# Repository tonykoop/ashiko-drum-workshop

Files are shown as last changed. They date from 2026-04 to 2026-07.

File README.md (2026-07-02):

# Ashiko Drum-Building Workshop

**Status:** L4 V5 empirical packet — validated by the 2015 workshop build of 16 drums. `validation.csv` captures nominal shell/head parameters; measured pitch values are pending re-measurement (workshop tuner readings were not recorded). `reference/acoustic-validation-checklist.md` defines pre-build and post-build acceptance gates.

> *In January 2015, I designed and led an 8-person workshop at a Twin Cities makerspace where we built 16 traditional African ashiko drums end-to-end — from sourcing raw hardwood lumber to lacing on the goatskin head.*

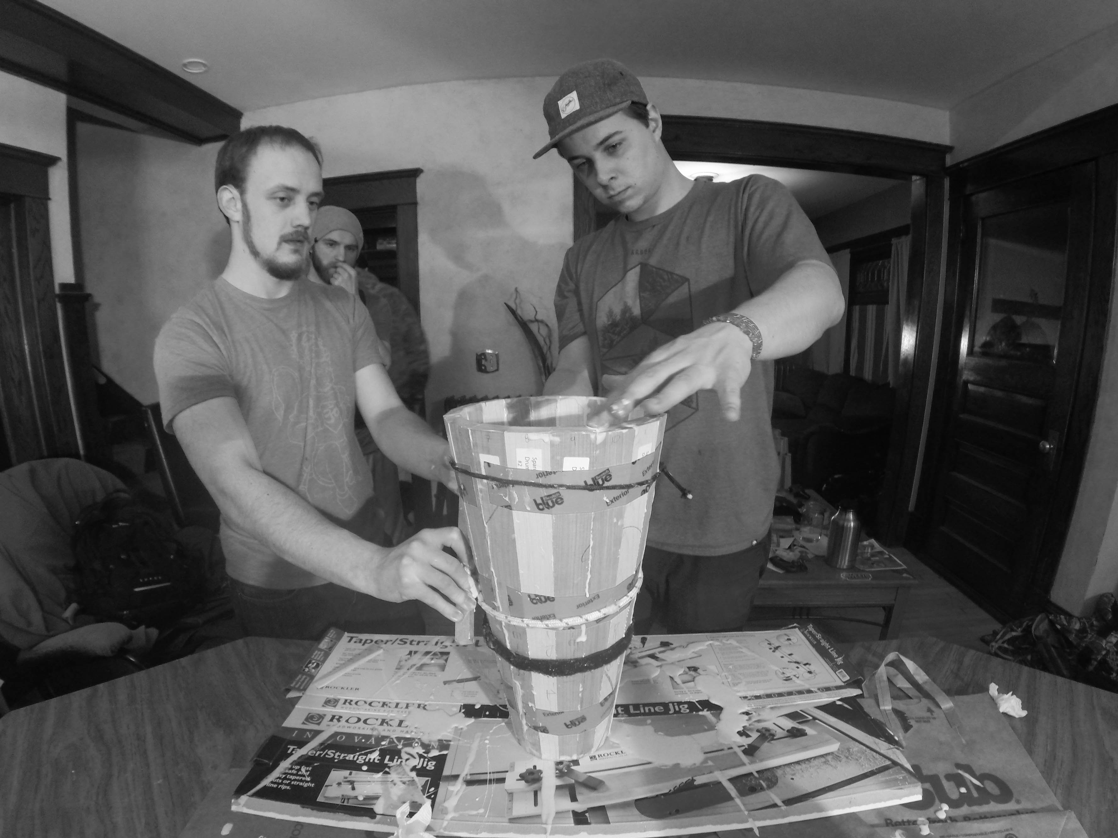
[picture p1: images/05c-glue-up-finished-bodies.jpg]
Hero photo


## What this is

An archive of the engineering and process documentation behind a workshop I designed and led at a Minneapolis makerspace in January 2015. Seven friends — most of whom had never used a table saw or a wood lathe — built sixteen full-scale ashiko hand drums together over several weeks.

This repository contains the things we needed to make that work: bills of material, CAD geometry, custom lathe-fixture drawings, the table-saw sled jig used for compound stave cuts, per-builder customization, and photos from the build. It is part build log, part teaching artifact, part portfolio piece.

For a flat-panel woodworking project that uses the same segmented glue-up discipline in a very different form, see [`chessboard-table`](https://github.com/tonykoop/chessboard-table).

## Background

The ashiko is a West African hand drum of Yoruba origin, traditionally carved or staved hardwood with a goatskin head — its sound sits between the deeper tone of a djembe and the brighter tone of a conga.

A few years before this workshop, I worked at **Morgan Drums**, a small St. Paul, MN family company building African hand drums — djembes, ashikos, bongos, and frame drums. That is where I learned the craft side: how to read a stave, how to read a goatskin, how a drum's tone changes between the lathe pass and the rope pull.

By late 2014 I was a member at a Twin Cities makerspace and convinced seven friends to spend a winter building drums with me. None of them were drum makers. The fun of it — and the engineering challenge — was designing a process robust enough that a bakery chef, a software salesman, and a yoga teacher could each produce a tuneable, beautiful drum on their first attempt.

## The process

The build runs through eight stages. Each stage has its own engineering choice tucked inside it.

| Stage | What we did | Engineering note |
|---|---|---|
| 1. Lumber sourcing | Bought board feet of cherry, hard maple, padauk, and purpleheart at Youngblood Lumber | Bulk pricing changed the BOM dramatically — see "BOM evolution" below |
| 2. Stave draft | "Drafted" the lumber across builders so each drum had a balanced wood mix | See `BOM/Stave-Draft-Rounds-1-7.pdf` |
| 3. Compound stave cuts | Cut 18 staves per drum on a Bosch 4100 table saw with a custom sled | Sled jig CAD in `CAD/table-saw-sled/` |
| 4. Glue-up | Two-half clamping fixture, Titebond III, ratchet straps | High-res photos in `/images/05*` |
| 5. Lathe turning | Custom keyed steel drive shaft + collar flange + 5/8" arbor → 60° cone adapter | All in `CAD/lathe-fixture/` |
| 6. Sanding & finishing | Progressive grits, then lacquer | — |
| 7. Ropework | 3/16" double-braided polyester rope, ~100 ft per drum | — |
| 8. Goatskin head | One large hairless goatskin per drum, soaked, mounted, tuned | — |

## Engineering artifacts

### Stave geometry

Three iterations of the 19-inch stave part lived in CAD before the workshop started. `19in-Stave-V3.SLDPRT` is the version we cut against. The V3 drawing (`19in-Stave-V3.SLDDRW`) is the one I'd hand a builder.

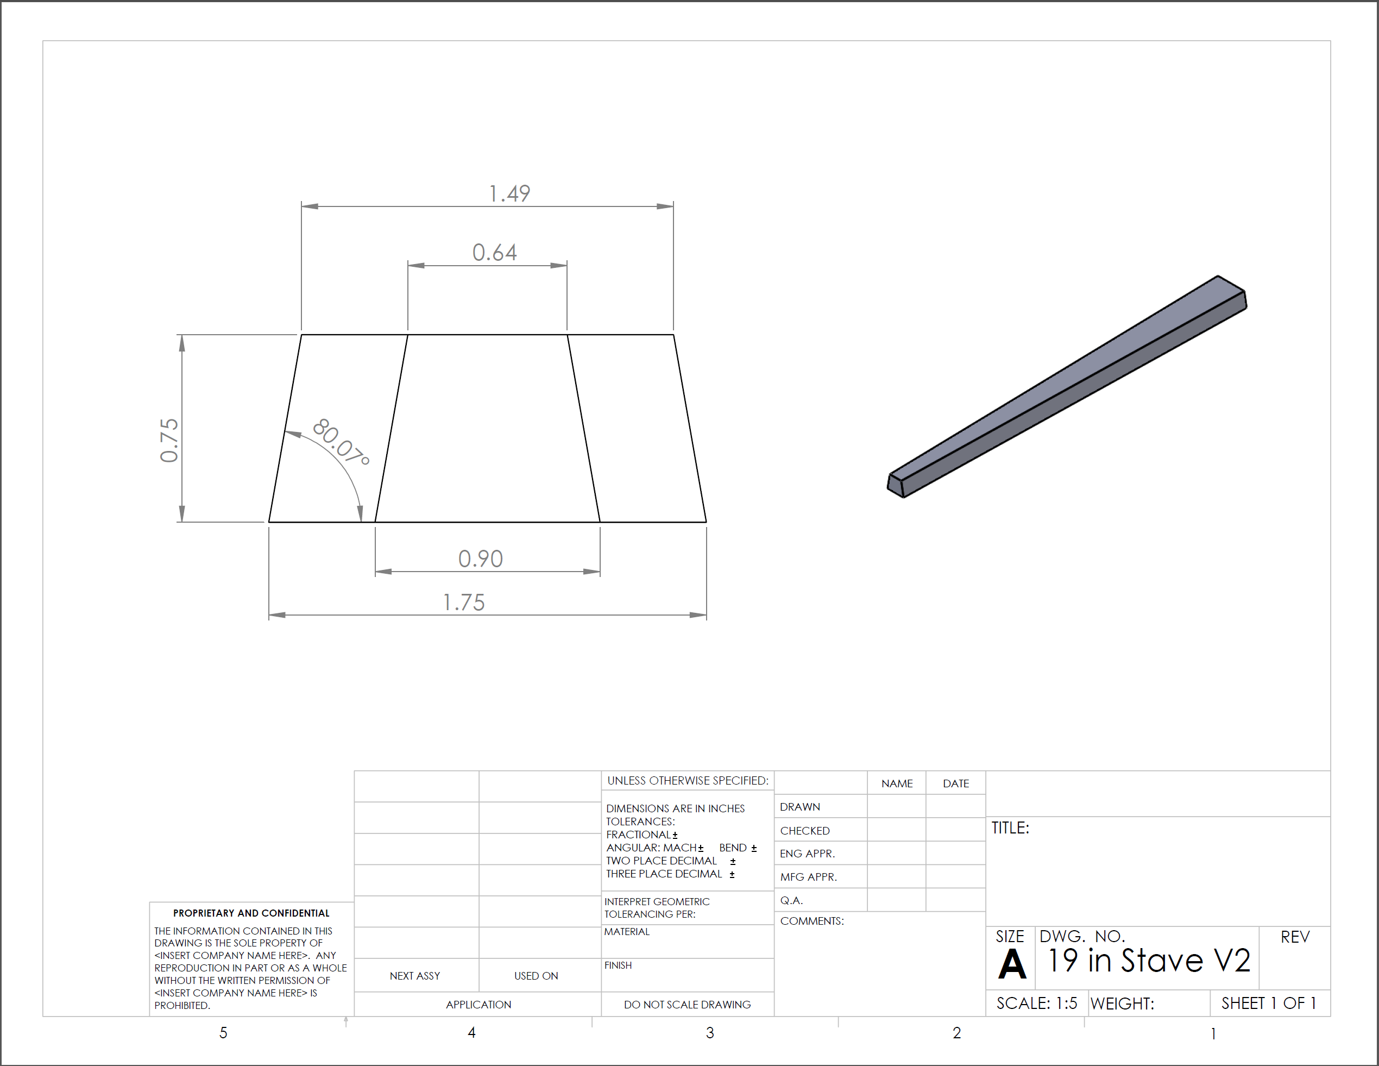
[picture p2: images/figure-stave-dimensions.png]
Stave dimensions


### Recovered segmented ashiko archive

A separate segmented-turning branch of the ashiko work has now been recovered into `CAD/segmented-ashiko/`, split into `large/` and `small/` studies. These are not the same thing as the 18-stave workshop build process documented elsewhere in this repo. They preserve an alternate geometry path where the shell is approximated as stacked segmented rings rather than long staves.

That makes the archive useful for two reasons: it keeps the ashiko-specific segmented work from being buried inside the djembe repo, and it shows how the same design questions were being explored across multiple related drums rather than as isolated one-off experiments.

### The table-saw sled jig

The single most engineering-heavy artifact in the project. Cutting 18 staves each with two compound miter cuts, two chop saw cuts, repeatably, ~72 cuts per drum × 16 drums, on a portable contractor saw, with eight different operators of varying experience — this is what made the workshop teachable. The sled assembly broke down into four parts:

- `Base-Board.SLDPRT` — the sled deck
- `Rib.SLDPRT` — the angled fence
- `Dowel.SLDPRT` and `Dowel-Holder.SLDPRT` — index pins for repeatable stave alignment

The reference document we built from is in `reference/Table-Saw-Sled-Construction-Reference.pdf`, with the table-saw owner's manual alongside in `reference/Bosch-4100-Table-Saw-Manual.pdf`.

### Glue-up — labeled staves, two-half clamping

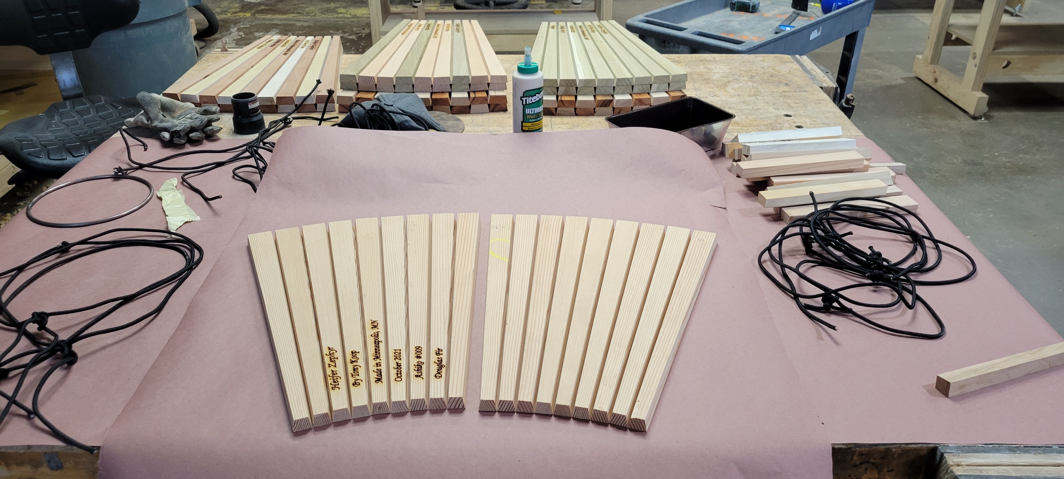
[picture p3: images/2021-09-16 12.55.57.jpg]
Glue-up prep: two half-rounds of labeled Douglas Fir staves laid flat, with clamping rope, glue, and earlier finished bodies behind

*Glue-up prep for **Ashiko #009 "Mister Zephyr"** — a Douglas Fir personal build from October 2021, six years after the workshop. The two fan-shaped half-rounds in the foreground are the eighteen staves split into two nine-stave assemblies; gluing as halves (then mating the two halves) is dramatically easier than trying to close a full eighteen-stave ring in one pass. The handwritten text on the inside faces of the left half-round — visible here, invisible once the drum closes up — is the maker's signature ("Mister Zephyr · © Tony Koop · Made in Minneapolis MN · October 2021 · Ashiko #009 · Douglas Fir"), a tradition continued from my Morgan Drums tenure (the same convention shows up in the [`djembe`](https://github.com/tonykoop/djembe) sister repo). Behind the work surface: Titebond III, the rope used for clamping pressure, and several finished glued bodies from earlier builds. **Why this photo earns a place in the workshop README:** the workshop ran in 2015. This drum was built solo in 2021. The CAD, BOM, sled jig, lathe fixture, and per-stage process documented in this repository were good enough that they're still producing drums six years later — that's the design-for-reproducibility outcome the workshop was originally built to test.*

### The lathe fixture

To turn a glued-up 18-stave drum body on a wood lathe without it walking, you need a custom drive arrangement that grips internally and transfers torque cleanly. The lathe fixture in `CAD/lathe-fixture/` includes:

- A 1-inch keyed steel drive shaft — two revisions, V1 → V2
- A 1-inch collar flange to interface the shaft with the lathe headstock
- A 5/8" arbor → 60° cone adapter (custom turned, drawing exported as PDF)
- The full `Ashiko-Turning-Assembly.SLDASM` showing how it all stacks up

McMaster-Carr referenced parts (for the bearings, fasteners, and bushings used in the fixture) are in `CAD/components/` keyed by their McMaster part number for reproducibility.

### Drum body iteration

The drum body went through six numbered revisions across roughly a year, from `Ashiko-REV010715.SLDPRT` (January 7, 2015 — first cut) through `Ashiko-REV012316.SLDPRT` (January 23, 2016 — post-workshop refinements after listening to all 16 finished drums). Iteration log lives in the file timestamps and the V1/V2/V3 forks in between.

### BOM evolution

The bill of materials went through two formal revisions during planning. The headline change: **estimated cost dropped from $135 to $78 per drum** between V1 and V2, primarily because we negotiated bulk pricing on hardwood lumber by buying for all eight builders at once, then "drafted" the boards across drums to keep each drum's wood mix interesting.

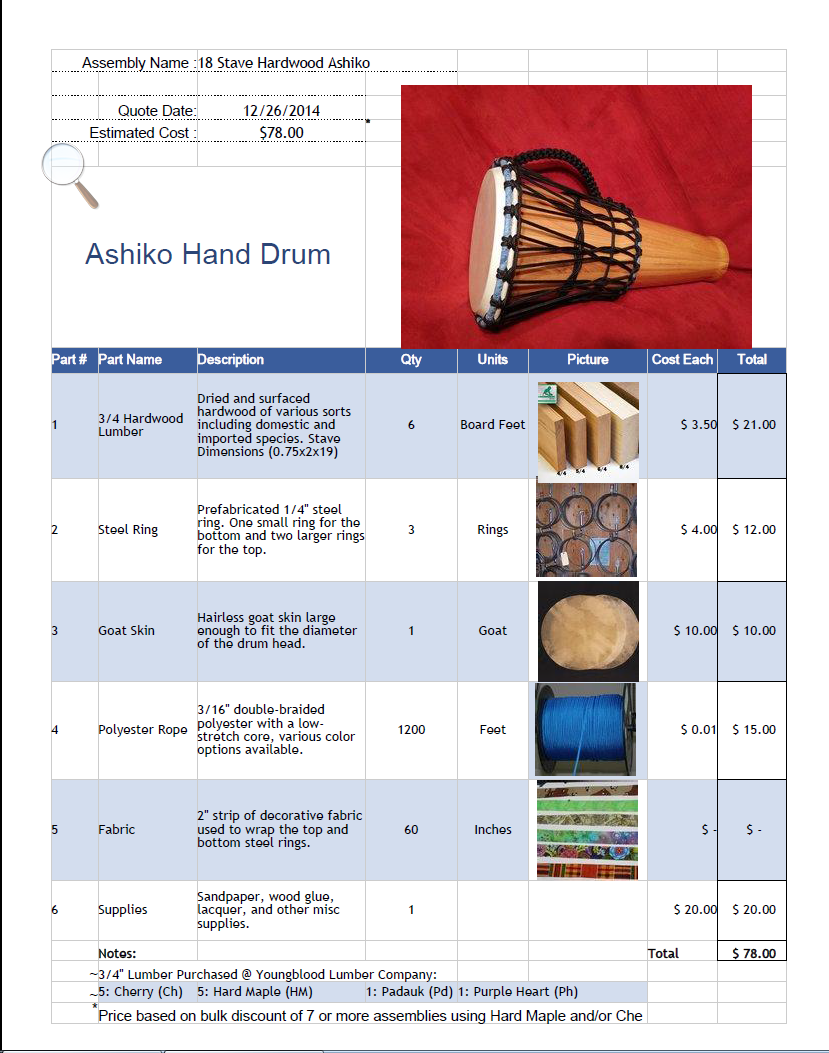
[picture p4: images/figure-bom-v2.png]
BOM V2


The full BOM PDFs are in `/BOM/`, including the lumber-share spreadsheet that tracked how much cherry/maple/padauk/purpleheart each builder ended up with.

### Per-builder drawings

Each builder got a personalized stave-cut drawing showing exactly which boards their staves came from and what order to cut them. These are in `/drawings/` (`Drawings-Tony-Dallas-Joe.pdf`, `Drawings-Max-Tyler-Dan.pdf`, `Drawings-Mike-Spare.pdf`, plus spare-drum drawings).

We also printed Avery 5160 labels for every stave so they didn't get mixed up between cut and glue-up — the label sheet template is `drawings/Stave-Labels-Avery-5160.pdf`.

## What I learned from running this

A few things that translate directly to the engineering work I do now:

- **Process design beats individual skill.** Even the most novice builder produced a drum indistinguishable from the most experienced builder's. That happened because the jigs and fixtures absorbed the variance, not because everyone became equally skilled. Same principle as Design for Manufacturability — the process should make the tolerance, not the operator.
- **Documentation is leverage.** The per-builder cut drawings, the labeled staves, the BOM revisions — without those, eight people working in parallel would have produced sixteen subtly different drums. With them, we produced sixteen drums to the same spec and learned far more about why drums sound how they do.
- **Iteration is cheap on the CAD side, expensive on the lumber side.** Six drum body revisions cost me a few weekends in SolidWorks. Cutting the wrong stave angle would have cost a board-foot of cherry per mistake. Front-load the iteration where it's free.

## Builders

Tony · Dallas · Dan E. · Dan P. · Joe · Max · Mike · Tyler

## License

Released under [CC-BY 4.0](LICENSE) — use freely with attribution. The drum design itself draws on traditional ashiko geometry; the CAD, drawings, photos, and process documentation in this repository are my work, free to reuse and adapt with credit.

## Repository structure

```
ashiko-drum-workshop/
├── README.md                  ← you are here
├── LICENSE                    ← CC-BY 4.0
├── .gitignore
├── BOM/                       ← bills of material, lumber draft
├── CAD/
│   ├── stave/                 ← 18-stave geometry, V1 → V3
│   ├── drum-body/             ← 6 numbered revisions of the assembled body
│   ├── segmented-ashiko/      ← recovered large + small segmented studies
│   ├── lathe-fixture/         ← drive shaft, collar, cone adapter, full assembly
│   ├── table-saw-sled/        ← compound-cut sled jig (4 parts)
│   └── components/            ← McMaster-Carr referenced parts
├── drawings/                  ← per-builder stave cut PDFs + Avery 5160 labels
├── images/                    ← curated build photos + figures
├── CAD/ashiko-drum-workshop.scad  ← parametric stave-shell envelope master (pending_measurement)
├── evolution/                 ← StudioPipeline Stage-0 intake (design intent, master manifest, revisions)
└── reference/                 ← Bosch 4100 saw manual, sled construction reference
```

Root-level V5 baseline packet files (`design.md`, `bom.csv`, `sourcing.csv`, `cut-list.csv`,
`validation.csv`, `risks.md`, `drawing-brief.md`) mirror the authored packet in `build/packet/`.

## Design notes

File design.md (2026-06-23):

# Ashiko Drum-Building Workshop — Design Packet

**Status: L4 V5 empirical packet** — validated by the 2015 workshop build of 16 drums.
Controlling authority: `CAD/drum-body/` SolidWorks parts + stave-cut drawings in `drawings/`.
Pitch measurements pending re-capture (workshop tuner readings were not recorded; see `validation.csv`).

## Instrument summary

The ashiko is a West African hand drum of Yoruba origin — conically tapered staved hardwood shell,
goatskin head, rope-mali tuning. Tone character sits between djembe (deeper, resonant bass) and
conga (brighter, more percussive attack). The workshop format produced 16 drums across 8 builders
over three Saturdays in January–February 2015 at a Twin Cities makerspace.

## Target geometry

| Parameter | Standard | Maple variant | Authority |
|---|---|---|---|
| Stave count | 18 | 18 | Workshop drawings |
| Shell OD at head | 279 mm (11 in) | 292 mm (11.5 in) | `CAD/drum-body/Ashiko-REV012316.SLDPRT` |
| Shell height | 610 mm (24 in) | 610 mm | Workshop drawing set |
| Tall variant height | 622 mm | — | `validation.csv` rows ASH-011/012 |
| Stave face bevel | 10° per face (20° included) | 10° per face | Derived from n=18 staves |
| Stave width (nominal, flat approx.) | ~48.7 mm | ~51.0 mm | Computed: π·D / n |
| Head bearing edge OD | flush with shell OD | flush | Lathe-turn to final |
| Head diameter (soaked, mounted) | 254 mm (10 in) | 267 mm (10.5 in) | BOM V2 |
| Rope | 3/16" double-braided polyester | same | BOM V2 |
| Finish | oil + lacquer | same | Workshop process |

## Stave geometry — compound miter method

The shell is a truncated cone approximated with flat staves. Each stave has:
- **Miter angle** (cut angle in the fence direction): derived from the taper half-angle
- **Bevel angle** (tilt of the blade): derived from the stave count (n=18 → 10°)

See `skills/stave-construction-compound-miter.md` for the general derivation.
The specific cut parameters used in the workshop are encoded in the SolidWorks part
`CAD/CNC Sled/Ashiko Stave REV012316.SLDPRT` and documented in `drawings/Stave-Cutting-Process.pdf`.

## Jig and fixture authority

| Fixture | CAD authority | Notes |
|---|---|---|
| Table-saw sled | `CAD/table-saw-sled/` SLDPRT set | Four parts: base-board, rib, dowel, dowel-holder |
| Lathe drive fixture | `CAD/lathe-fixture/` SLDASM | Keyed shaft V2, collar flange, cone adapter |
| Index sled | `CAD/CNC Sled/` SLDPRT set | Compound-angle stave-cut jig for ≤3° barrel-taper ashiko |

## Wood species

| Species | Shell color | Tone character | BOM note |
|---|---|---|---|
| Cherry | warm reddish | warm mid, good projection | Primary batch; ~10 drums |
| Hard maple | pale | bright, crisp attack | Used for slightly larger 292 mm variant |
| Walnut | dark brown | deep, mellow sustain | 2021 solo build (Ashiko #009) |
| Padauk | orange-red | high brightness | Mixed into stave drafts |
| Purpleheart | purple | very bright | Accent staves only |

## Design decisions recorded

1. **18-stave count**: chosen as smallest count that keeps individual stave width manageable on a 10–12" drum without over-compounding the bevel angle. Gives ≈48 mm stave face, comfortable to handle and clamp.
2. **Two-half glue-up**: closing 18 staves as two 9-stave half-rounds, then mating the halves, proved dramatically more reliable than full-ring clamping for first-time builders.
3. **Rope-mali tuning**: retained traditional method over metal hardware — reduces cost, is repairable in the field, and allows head re-tensioning without tools.
4. **Lathe fixture design**: internal keyed drive shaft avoids marring the outside of the shell and transfers torque without slippage. Full SolidWorks assembly in `CAD/lathe-fixture/`.
5. **Stave-draft BOM**: buying lumber in bulk for all 8 builders cut per-drum cost from ~$135 to ~$78 by enabling volume discounts and efficient board utilization across the batch.

## Open measurement gates (L4 → public-build-ready)

- Pitch re-measurement: none of the 16 workshop drums had post-build pitch recorded with a tuner.
  Re-measurement requires physical access to the drums (contact builders).
- Out-of-round characterization: shell OD check data was not recorded numerically (go/no-go only).
- Goatskin provenance: supplier and batch ID not recorded for the 2015 build.

These gates do not block further builds from this packet but are noted in `validation.csv`
and `reference/acoustic-validation-checklist.md`.

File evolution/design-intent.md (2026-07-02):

# Design Intent — ashiko-drum-workshop rev A

- Master CAD: `CAD/ashiko-drum-workshop.scad` (sha256: 3d7b2cb07bc485b7999f87ff7a288264ec39a5a2cf3f64bfc15d8043c1f43e45), envelope driven by `ashiko-drum-workshop-design-table.xlsx` (sha256: d6d778341f5a2d4ffbb70eaf88692447e9b2117a7af8be7361242dee5e701dc7) and the `CAD/drum-body/` SolidWorks parts (dimensional authority).
- Function: West African ashiko hand drum — conically tapered staved hardwood shell (18 staves) with a goatskin head under rope-mali tension. Tone sits between djembe (deeper bass) and conga (brighter attack). Empirically validated by the 2015 workshop build of 16 drums across 8 builders.
- Environment: hand-played acoustic membranophone; solid-wood staved shell moves with humidity; rope-mali system carries sustained head tension. Head is a tuned load path.
- Target qty: 1 (prototype reference; workshop historically produced 16). Deadline: TBD. Budget/unit ceiling: TBD.

## Critical dimensions (carry tolerances)

| Feature | Nominal | Tolerance | Why critical | Source |
| --- | --- | --- | --- | --- |
| Stave count | 18 | dry-fit all 18 in a ring before glue | shell roundness / bevel accumulation | design.md Target geometry (Workshop drawings) |
| Shell OD at head | 279 mm (11 in) std / 292 mm (11.5 in) maple | lathe-turn to final, flush bearing edge | head seating / OD | design.md (CAD/drum-body/Ashiko-REV012316.SLDPRT) |
| Shell height | 610 mm (24 in) | cut-list gate | proportion / air column | design.md Target geometry |
| Stave face bevel | 10 deg per face (20 deg included) | reference-gauge set per batch | shell roundness | design.md (derived from n=18) |
| Stave face width | pi*D/n ≈ 48.7 mm (std) | caliper vs computed | ring closure | design.md "Computed: pi*D/n" |
| Head diameter (soaked, mounted) | 254 mm (10 in) std / 267 mm maple | soak/mount procedure | tunable pitch | design.md (BOM V2) |
| Foot OD | assumption (~190 mm) — NOT tabulated | measurement required | taper / stance | .scad assumption; PENDING MEASUREMENT |

## Incidental (free for DFM)

- Wood species selection and stave draft mix (cherry/maple/walnut/padauk/purpleheart), external finish, cosmetic rope-wrap pattern, foot styling below the resonating body.

## Must-nots (DFM may never violate)

- Do not let stave bevel drift across the 18-stave batch — reset the sled against a reference bevel gauge each drum and dry-fit the full ring before glue (risks.md R1).
- Do not attempt a single-pass 18-stave glue-up; close as two 9-stave half-rounds within Titebond III open time (risks.md R2).
- Do not run the lathe without the keyed drive shaft fully seated in the headstock taper — walk damages the bearing edge (risks.md R3).
- Do not treat the .scad foot_od / wall / bearing-edge band as fabrication dimensions — they are assumptions pending measurement of the SolidWorks masters.

## Material intent

- Preferred: staved hardwood shell (cherry primary; hard maple for the larger variant) per bom.csv; goatskin head; 3/16 in double-braided polyester rope; oil + lacquer finish.
- Acceptable subs: per sourcing.csv (spec-first; live prices unverified).
- Forbidden: none recorded.

## Stage status

Stage 0 intake complete 2026-07-01. Gate A (Alpha shop compile) NOT yet run — no concessions logged, nothing presented as shippable. L4 empirical status preserved (backed by the 2015 build); this pass added only the envelope master, provenance, and intake.

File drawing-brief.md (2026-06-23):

# Ashiko Drum-Building Workshop — Drawing Brief

## Priority drawings needed for public build authority

### D1 — Stave geometry detail (HIGH)
**Purpose:** Builder can verify stave cut angles without SolidWorks.
**Contents:** Stave face width (48.7 mm / 51.0 mm for maple variant), bevel angle (10°),
miter angle per drum taper, length (610 mm / 622 mm), and grain direction.
**Source CAD:** `CAD/CNC Sled/Ashiko Stave REV012316.SLDPRT`
**Status:** SolidWorks drawing exists (`CAD/CNC Sled/Drawings/`); needs DXF export.

### D2 — Shell cross-section with head-bearing detail
**Purpose:** Shows how stave edges meet, bearing-edge radius, and hoop seat geometry.
**Contents:** Half-section of assembled shell at head end; OD, wall thickness at bearing edge,
and edge radius target.
**Source CAD:** `CAD/drum-body/Ashiko-REV012316.SLDPRT` (assembled cross-section)
**Status:** Not yet exported as standalone drawing.

### D3 — Lathe fixture assembly (MEDIUM)
**Purpose:** Builder can fabricate or commission the keyed-shaft fixture without SolidWorks.
**Contents:** Shaft OD, keyway dimensions, flange bolt pattern, cone adapter profile.
**Source CAD:** `CAD/lathe-fixture/Ashiko-Turning-Assembly.SLDASM`
**Status:** Partial PDF exports exist in `CAD/lathe-fixture/`; no complete dimensioned drawing.

### D4 — Table-saw sled assembly (MEDIUM)
**Purpose:** Allows reproduction of the compound-angle stave sled.
**Contents:** Base board dimensions, rib angle, dowel spacing, fence position.
**Source CAD:** `CAD/table-saw-sled/` SLDPRT set
**Status:** Reference PDF in `reference/Table-Saw-Sled-Construction-Reference.pdf`; needs
dimensioned CAD drawing export.

### D5 — Per-builder stave draft sheet (reference)
**Purpose:** Documents which boards each of the 8 builders received; historical reference.
**Source:** `drawings/Stave-Cutting-Process.pdf` (workshop document)
**Status:** Already exists as PDF; no conversion needed.

## Format notes

All DXF exports should be in AutoCAD 2013 format (AC1027) for broadest compatibility.
SVG previews can be derived from DXF via Inkscape for web display; mark as `derived_preview`
in `visual-output-register.csv`.

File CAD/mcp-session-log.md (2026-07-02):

# MCP / External-Tool Session Log

V5 provenance record for artifacts generated or modified by external tools.
Required before claiming any artifact came from OpenSCAD, Blender, Illustrator,
Photoshop, Fusion, SketchUp, Wolfram, or similar tooling.

| session_id | tool | input_authority | outputs | role | authority_result | review_status | notes |
|---|---|---|---|---|---|---|---|
| fable-v5-refresh-2026-07-01 | claude-code (Fable 5) | ashiko-drum-workshop-design-table.xlsx | design.md, bom.csv, sourcing.csv, cut-list.csv, validation.csv | packet_refresh | fabrication | self_checked | V5 refresh pass; tabular packet data reviewed against design table. Root baseline files mirror build/packet/ authored packet. No dimension changes made. Provenance rows added to satisfy V5 fabrication-artifact logging. |
| fable-v5-refresh-2026-07-01 | claude-code (Fable 5) + OpenSCAD CLI | ashiko-drum-workshop-design-table.xlsx, build/packet/design.md | CAD/ashiko-drum-workshop.scad | cad_authoring | pending_measurement | self_checked | Parametric stave-shell envelope master: stave_count=18, head OD 279 mm, shell height 610 mm, 10 deg bevel, stave_face_width = pi*D/n — all from design.md Target geometry. foot_od + wall are marked assumptions (not tabulated). Compound-miter stave cut + bearing-edge profile intentionally out of scope (hand-refined, live in SolidWorks). openscad render check: pass (openscad -o STL, exit 0). NOT fabrication authority until reviewed against SLDPRT masters. |
| fable-v5-refresh-2026-07-01 | claude-code (Fable 5) | Mersenne-Taylor circular membrane model | wolfram/ashiko-wolfram-model.wl | analysis_source | derived_preview | unreviewed | Source-only membrane tension / fundamental-frequency model; not executed. L2 evidence only. |

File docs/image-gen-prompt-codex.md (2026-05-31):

# Ashiko Drum Workshop Image-Gen Prompts

Concept visualization only; not fabrication authority. Do not infer stave
angles, fixture dimensions, head sizes, or rope lengths from these prompts.

## Hero Prompt

Photorealistic 3/4 product photograph of a finished stave-built ashiko hand drum from the workshop archive: a tall tapered hardwood shell made from many vertical staves in cherry, hard maple, padauk, and purpleheart tones, lathe-turned smooth, finished in clear lacquer, with a natural goatskin head and taut polyester rope tuning around the rim. Show the conical ashiko silhouette, crisp stave seams, clean bearing edge, and workshop-made character, with a soft hand-drum mallet or table-saw sled off to one side for scale. Clean studio background, soft directional lighting, 50mm lens, high detail, photorealistic.

## In-Context Prompt

Photorealistic makerspace workshop scene from an ashiko-building class: several partially finished stave shells on benches, labeled staves, ratchet straps or rope clamps, a table-saw sled nearby, and one finished ashiko being tuned with goatskin and rope. People may be present as careful adult builders, but hands must look natural and safety-aware. Warm shop light, sawdust, clamps, lathes and jigs in the background, documentary realism.

## Detail / Macro Prompt

Photorealistic macro close-up of the ashiko's construction signature: alternating hardwood staves meeting in clean vertical seams, the shell curve transitioning into a smooth bearing edge, goatskin folded over the rim, and braided rope crossing through the tuning pattern. Show lacquer sheen, wood grain, small handmade variation, and real tension in the rope. High-detail macro, shallow depth of field.

## Negative / Avoid

No text, logos, watermarks, impossible rope paths, unsafe tool use, extra limbs, distorted hands, fake labels, or culturally generic fantasy decoration.

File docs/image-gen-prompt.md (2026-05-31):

# Image-Gen Prompts

Concept image only; not fabrication authority. Do not include cut-ready dimensions, hole locations, or toolpaths.

## Hero Prompt

A finished traditional West African ashiko hand drum standing upright as a real physical object: a tall truncated-cone shell, wide at the goatskin head and tapering to a narrow open foot, built from eighteen vertical hardwood staves glued into a seamless conical body. The staved construction reads clearly through the finish — alternating warm tones of cherry, hard maple, deep red padauk, and violet-brown purpleheart running as long vertical strips up the cone, lacquered to a soft satin sheen that catches the light. A single hairless goatskin head is stretched taut across the wide top, laced down with fine cream double-braided polyester rope in a vertical V-pattern of pulls running around the upper shell, gathered into a tuning weave near the rim. Realistic drum scale, roughly knee-to-thigh height, sitting on a clean neutral light-gray studio sweep. Soft directional studio light from upper left, gentle falloff, 3/4 product-photography angle, ~50mm lens, high detail, photorealistic, no text labels.

## In-Context Prompt

The same staved hardwood ashiko drum staged in a warm makerspace woodshop: tilted slightly forward and held between the knees of a seated player in the West African playing posture, hands resting on the goatskin head mid-strike. Background shows soft out-of-focus shop detail — a wood lathe, ratchet straps and clamps on a bench, several other finished multi-wood drum bodies waiting in a row — telling the story of a group build. Natural window light raking across the rope lacing and the vertical grain of the staves, shallow depth of field, environmental storytelling, concept visualization only.

## Detail Prompt

Macro close-up of the upper shell where the goatskin head meets the staved hardwood body: the taut translucent goatskin lapped over the rim, the fine cream double-braided polyester rope drawn into tight diagonal pulls and a tuning weave, and the precise glue seams between adjacent cherry, maple, padauk, and purpleheart staves visible just below as crisp vertical joint lines. Raking low-angle light emphasizing the rope texture, the skin grain, and the satin-lacquered wood surface, high detail, no measurements.

## Negative / Avoid

No text, logos, watermarks, or fake maker marks; no dimension callouts or measurement lines; no impossible rope routing or floating hardware; anatomically plausible hands if a player is shown.

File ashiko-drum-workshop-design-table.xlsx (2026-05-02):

Segmented Ashiko (Djembe-Style) — 464-Piece Diamond Pattern
29 Rings × 16 Segments · 4 Wood Species · Lathe-Turned Profile
DESIGN PARAMETERS |  |  | WOOD SPECIES
Segments per Ring | 16 |  | Maple | 132 | segments
Ring Thickness (in) | 0.875 |  | Walnut | 196 | segments
Miter Angle (°) |  | ← =180/segments | Cherry | 28 | segments
Overall Height (in) |  |  | Yellowheart | 108 | segments
Head Diameter (in) | 11.8 |  | Total
Waist Diameter (in) | 5.6
Bell Diameter (in) | 11.8 |  | Diamond pattern: Maple/Walnut
Total Pieces |  |  | base with Cherry/Yellowheart accents
RING-BY-RING CUT LIST
Ring | Board W | Board L | S.E.L. | Outer Ø | Maple | Walnut | Cherry | Yellow | Zone
1 | 1.00 | 16.1 | 1.559 | 7.8 | 8 | 0 | 0 | 8 | Top (bowl)
2 | 1.00 | 16.7 | 1.527 | 7.6 | 0 | 8 | 0 | 8 | Top (bowl)
3 | 1.00 | 17.2 | 1.476 | 7.4 | 8 | 0 | 0 | 8 | Top (bowl)
4 | 1.00 | 17.8 | 1.436 | 7.2 | 0 | 4 | 0 | 4 | Top (bowl)
5 | 1.00 | 18.4 | 1.396 | 7 | 8 | 0 | 0 | 8 | Top (bowl)
6 | 1.00 | 18.8 | 1.353 | 6.8 | 0 | 8 | 0 | 8 | Top (bowl)
7 | 1.00 | 19.1 | 1.313 | 6.6 | 8 | 0 | 0 | 8 | Top (bowl)
8 | 1.00 | 19.0 | 1.277 | 6.4 | 0 | 4 | 0 | 4 | Top (bowl)
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

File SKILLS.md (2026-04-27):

# Skills demonstrated in this repo

> *A human-readable index of the reusable build and geometry methods documented in the ashiko workshop repository.*

## Stave construction

- **[stave-construction-compound-miter](skills/stave-construction-compound-miter.md)** *(canonical: this repo)* — turn a target shell diameter and stave count into cuttable stave geometry and a repeatable table-saw setup.

## Cross-repo links

- [`djembe`](https://github.com/tonykoop/djembe) grows out of the same family of stave-construction problems, but with a more complicated goblet profile.
- [`dundun`](https://github.com/tonykoop/dundun) simplifies the same method down to a constant-angle cylindrical case.
- [`chessboard-table`](https://github.com/tonykoop/chessboard-table) is a furniture-scale example of the same segmented glue-up discipline in a flat panel instead of a drum shell.

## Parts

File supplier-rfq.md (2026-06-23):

# Supplier RFQ — Ashiko Drum-Building Workshop

> **Status: placeholder** — populate with confirmed part numbers, quantities,
> and quoted lead times before placing orders.

## How to use this file

Send relevant sections to suppliers; combine into a single email RFQ where the
supplier handles multiple line items.  Record quote date and contact in the
notes column of `sourcing.csv`.

## Part Requests

| Part | Specification | Qty | Target price | Notes |
|---|---|-----|---|---|
| Head | TBD diameter, natural goatskin or synthetic | TBD | TBD | Confirm fit with shell OD |
| Shell stock | TBD species, thickness, board-feet | TBD | TBD | Per cut-list.csv |
| Tensioning hardware | TBD style (rope / lug / rod) | TBD | TBD | Per design.md |
| Counter-hoop | TBD diameter, steel or wood | TBD | TBD | Match head OD |
| Finish | TBD (oil / wax / shellac) | TBD | TBD | Food-safe if skin contact |

## Preferred Suppliers

*(Populate from `sourcing.csv` when confirmed)*

## Lead-Time Notes

- Natural-skin heads: 2–4 weeks if not in stock; order first.
- Hardwood shell stock: check Woodcraft / Hearne Hardwoods / local sawmill.
- Hardware: check Remo / LP / Toca for drum hardware; hardware stores for rod stock.

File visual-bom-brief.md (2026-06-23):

# Visual BOM Brief — Ashiko Drum-Building Workshop

> **Status: placeholder** — replace rendered placeholder images with actual
> build photos at L3 promotion.

## Purpose

This brief defines the visual-BOM assembly image requirements: one hero render
or photo per major assembly and one close-up per critical joint or hardware
detail.

## Hero Assembly Image

- **Required:** one full instrument view showing finished assembly.
- **Current status:** AI-generated concept render (non-dimensional authority).
- **Acceptance:** replace with a photograph of the first finished prototype.

## Part-Level Images

| Part | Image required | Authority | Notes |
|---|---|---|---|
| Shell / body | Yes | concept only | Show stave pattern or sheet metal form |
| Head + hoop | Yes | concept only | Show tensioning hardware |
| Hardware detail | Yes | concept only | Lug / rope / rod close-up |
| Finished instrument | Yes | prototype photo | Primary visual BOM entry |

## Image Conventions

- Shoot on a neutral background (white or grey paper sweep).
- Include a scale reference (rule or known object) in at least one shot.
- Label files: `ashiko-drum-workshop-[part]-[sequence].jpg` (e.g., `ashiko-drum-workshop-shell-01.jpg`).
- Record each image in `visual-output-register.csv` with its authority label.

*See `photo-shotlist.md` for the shot list tied to build stages.*

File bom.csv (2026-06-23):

part_id | description | qty_per_drum | unit | unit_cost_usd_2015 | total_cost_usd_2015 | supplier | notes
LBR-CHR | Cherry hardwood lumber (4/4 surfaced) | 4 | board_foot | 4.50 | 18.00 | Youngblood Lumber Minneapolis | Bulk pricing negotiated; stave billets 2x48 in each
LBR-MAPl | Hard maple hardwood lumber (4/4 surfaced) | 2 | board_foot | 3.75 | 7.50 | Youngblood Lumber Minneapolis | Used for wider 292 mm variant drums
LBR-PAD | Padauk hardwood (4/4 surfaced) | 0.5 | board_foot | 8.00 | 4.00 | Youngblood Lumber Minneapolis | Accent stave splices; small quantity per drum
LBR-PUR | Purpleheart hardwood (4/4 surfaced) | 0.25 | board_foot | 9.00 | 2.25 | Youngblood Lumber Minneapolis | Accent stave splices; very small quantity
HEAD-GSK | Goatskin drum head (hairless | pre-cut circle) | 1 | each | 14.00 | 14.00 | African Rhythm Imports or local drumming supplier | Soaked before mounting; 25 mm wrap allowance beyond shell OD
ROPE-3_16 | 3/16" double-braided polyester rope | 100 | foot | 0.06 | 6.00 | Hardware store / rope supplier | ~100 ft per drum for mali weave; check tension consistency
HOOP-WD | Wood hoop (steam-bent ash or oak ring) | 1 | each | 4.00 | 4.00 | Sourced or shop-bent from 3/4 in ash strip | Head is wrapped over this hoop before lacing
GLUE-T3 | Titebond III wood glue | 0.25 | pint | 3.00 | 0.75 | Woodcraft or hardware store | Waterproof; used for stave glue-up
LACQ-OIL | Oil + lacquer finish (Tung oil + spray lacquer) | 0.125 | quart | 6.00 | 0.75 | Hardware / finishing store | Two coats oil + two coats lacquer; sanded between
SAND-SET | Sandpaper assortment (80/120/180/220 grit) | 1 | set | 2.00 | 2.00 | Hardware store | Progressive grits; finish with 220 before lacquer
SCREW-SET | Drywall screws 1-5/8" for clamping cauls | 6 | each | 0.05 | 0.30 | Hardware store | Temporary caul attachment; removed after glue cure
ROPE-CORD | Nylon cord for clamping (glue-up only) | 20 | foot | 0.02 | 0.40 | Hardware store | Rope-clamp around 9-stave half; reused across drums
TOTAL | Total materials per drum (2015 bulk pricing) | 1 | drum |  |  |  | ~$78 per drum at workshop scale; individual sourcing ~$110-135

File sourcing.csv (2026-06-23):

part_id | supplier_name | supplier_location | supplier_url | lead_time_days | min_order | notes
LBR-CHR | Youngblood Lumber | Minneapolis MN | https://www.youngbloodlumber.com | 1 | 1 board foot | Used for 2015 workshop; call ahead for 4/4 cherry availability; bulk discount available for 8+ builders
LBR-MAP | Youngblood Lumber | Minneapolis MN | https://www.youngbloodlumber.com | 1 | 1 board foot | Same supplier; 4/4 hard maple for 292 mm variant drums
LBR-PAD | Woodcraft or Rockler | National chain | https://www.woodcraft.com | 1-5 | 1 board foot | Padauk is specialty wood; Woodcraft carries reliably; exotic lumber dealers also carry
LBR-PUR | Woodcraft or Rockler | National chain | https://www.woodcraft.com | 1-5 | 1 board foot | Purpleheart accent staves; small quantity only
HEAD-GSK | African Rhythm Imports | Online | https://www.rhythmimports.com | 5-10 | 1 each | Pre-cut goatskin circles; specify head OD (254 mm for standard drum); salted/dry form preferred
HEAD-GSK-ALT | Drum-making suppliers | Online | https://www.drumsticksusa.com | 3-7 | 1 each | Multiple online suppliers for goatskin drum heads; ensure hairless grade
ROPE-3_16 | Knot & Rope Supply | Online | https://www.knotandrope.com | 3-7 | 100 feet | 3/16" double-braided polyester; black or natural; any color is functional
ROPE-3_16-ALT | West Marine | National chain |  | 1-3 | 100 feet | Marine-grade polyester rope; carries 3/16"; slightly higher cost
HOOP-WD | Shop-bent (ash or oak) | Local shop |  | 7-14 custom | 1 each | Bend from 3/4 x 3/4 in ash strip steam-bent to shell OD; or order from drum parts supplier
GLUE-T3 | Woodcraft or hardware store | Local | https://www.woodcraft.com | 1 | 1 pint | Titebond III; waterproof PVA; must be genuine Titebond III for moisture resistance
LACQ-OIL | Woodcraft or hardware store | Local |  | 1 | 1 quart | Tung oil (Waterlox or equivalent) + spray lacquer for topcoat
SAND-SET | Hardware store / online | Local |  | 1 | 1 set | Norton or 3M; 80/120/180/220 assortment

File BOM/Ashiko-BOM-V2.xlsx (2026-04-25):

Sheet: BillOfMaterials
 | Assembly Name : | 18 Stave Hardwood Ashiko |  |  | [42]
 | Quote Date: | 2014-12-26
 | Estimated Cost : | $78.00 | *
Ashiko Hand Drum
Part # | Part Name | Description | Qty | Units | Picture | Cost Each | Total
1 | 3/4 Hardwood Lumber | Dried and surfaced hardwood of various sorts including domestic and imported species. Stave Dimensions (0.75x2x19) | 6 | Board Feet |  | $3.50 | $21.00
2 | Steel Ring | Prefabricated 1/4" steel ring. One small ring for the bottom and two larger rings for the top. | 3 | Rings |  | $4.00 | $12.00
3 | Goat Skin | Hairless goat skin large enough to fit the diameter of the drum head. | 1 | Goat |  | $10.00 | $10.00
4 | Polyester Rope | 3/16" double-braided polyester with a low-stretch core, various color options available. | 1200 | Feet |  | $0.01 | $15.00
5 | Fabric | 2" strip of decorative fabric used to wrap the top and bottom steel rings. | 60 | Inches |  | $0.00 | $0.00
6 | Supplies | Sandpaper, wood glue, lacquer, and other misc supplies. | 1 |  |  | $20.00 | $20.00
 | Notes: |  |  |  |  | Total | $78.00
~ | 3/4" Lumber Purchased @ Youngblood Lumber Company:
~ | 5: Cherry (Ch) | 5: Hard Maple (HM) | 1: Padauk (Pd) | 1: Purple Heart (Ph)
* | Price based on bulk discount of 7 or more assemblies using Hard Maple and/or Cherry

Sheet: Revisions
Revision History
 | Assembly Name :
 | Assembly Number :
Revision | Revision Summary | Approval Date

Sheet: Example
Bill of Materials for LEGO® Design
 |  |  | http://www.vertex42.com/ExcelTemplates/free-timesheet-template.html |  |  |  |  |  |  | © 2012-2014 Vertex42 LLC
 |  |  | Assembly Name : | Mini X-Wing™ |  |  | [42] |  |  | Bill of Materials Template (http://www.vertex42.com/ExcelTemplates/bill-of-materials.html)
 |  |  | Assembly Number : | Custom
 |  |  | Assembly Revision :
 |  |  | Approval Date :
 |  |  | Pieces : | 46
 |  |  | Total Cost : | $5.85
Category | Part # | Elem ID | Part Name | Color | Qty | Units | Picture | Unit Cost | Cost
Bricks, Sloping | 50746 | 4504369 | ROOF TILE 1X1X2/3, ABS | 1 - White | 1 | each |  | $0.10 | $0.10
Plates | 3024 | 302401 | PLATE 1X1 | 1 - White | 1 | each |  | $0.10 | $0.10
Plates | 3023 | 302301 | PLATE 1X2 | 1 - White | 2 | each |  | $0.10 | $0.20
Plates | 3023 | 4211398 | PLATE 1X2 | 194 - Medium Stone Grey | 1 | each |  | $0.10 | $0.10
Plates | 3794 | 379401 | PLATE 1X2 W. 1 KNOB | 1 - White | 1 | each |  | $0.10 | $0.10
Plates | 3623 | 362301 | PLATE 1X3 | 1 - White | 1 | each |  | $0.10 | $0.10
Plates | 3623 | 362321 | PLATE 1X3 | 21 - Bright Red | 1 | each |  | $0.10 | $0.10
Plates | 94148 | 302201 | PLATE 2X2 | 1 - White | 1 | each |  | $0.15 | $0.15
Plates, Special | 6141 | 4210633 | PLATE 1X1 ROUND | 199 - Dark Stone Grey | 1 | each |  | $0.10 | $0.10
Plates, Special | 3070 | 307021 | FLAT TILE 1X1 | 21 - Bright Red | 4 | each |  | $0.10 | $0.40
Plates, Special | 2412 | 241201 | RADIATOR GRILLE 1X2 | 1 - White | 1 | each |  | $0.10 | $0.10
Plates, Special | 6019 | 4538353 | PLATE 1X1 W/HOLDER VERTICAL | 1 - White | 4 | each |  | $0.15 | $0.60
Plates, Special | 2431 | 4558168 | FLAT TILE 1X4 | 1 - White | 1 | each |  | $0.20 | $0.20
Plates, Special | 63868 | 4535737 | PLATE 2X1 W/HOLDER,VERTICAL | 1 - White | 4 | each |  | $0.15 | $0.60
Plates, Special | 2540 | 4211632 | PLATE 1X2 W. STICK | 194 - Medium Stone Grey | 4 | each |  | $0.15 | $0.60
Plates, Special | 3176 | 4225733 | COUPLING PLATE 2X2 | 199 - Dark Stone Grey | 1 | each |  | $0.20 | $0.20
Bricks, Special | 49668 | 4224793 | PLATE 1X1 W/TOOTH | 5 - Brick Yellow | 1 | each |  | $0.10 | $0.10
Technic | 32123 | 4211573 | 1/2 BUSH | 194 - Medium Stone Grey | 4 | each |  | $0.10 | $0.40
Technic | 6590 | 4211622 | BUSH FOR CROSS AXLE | 194 - Medium Stone Grey | 8 | each |  | $0.15 | $1.20
Accessories | 3957 | 4211473 | STICK/AERIAL | 194 - Medium Stone Grey | 4 | each |  | $0.10 | $0.40
 |  |  | Total |  | 46 |  |  |  | $5.85

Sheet: ©
Bill of Materials Template
By Vertex42.com
http://www.vertex42.com/ExcelTemplates/bill-of-materials.html
© 2012-2014 Vertex42 LLC
This spreadsheet, including all worksheets and associated content is considered a copyrighted work under the United States and other copyright laws.
Do not submit copies or modifications of this template to any website or online template gallery.
Please review the following license agreement to learn how you may or may not use this template. Thank you.
See License Agreement (http://www.vertex42.com/licensing/EULA_privateuse.html)
http://www.vertex42.com/licensing/EULA_privateuse.html
Do not delete this worksheet. If necessary, you may hide it by right-clicking on the tab and selecting Hide.

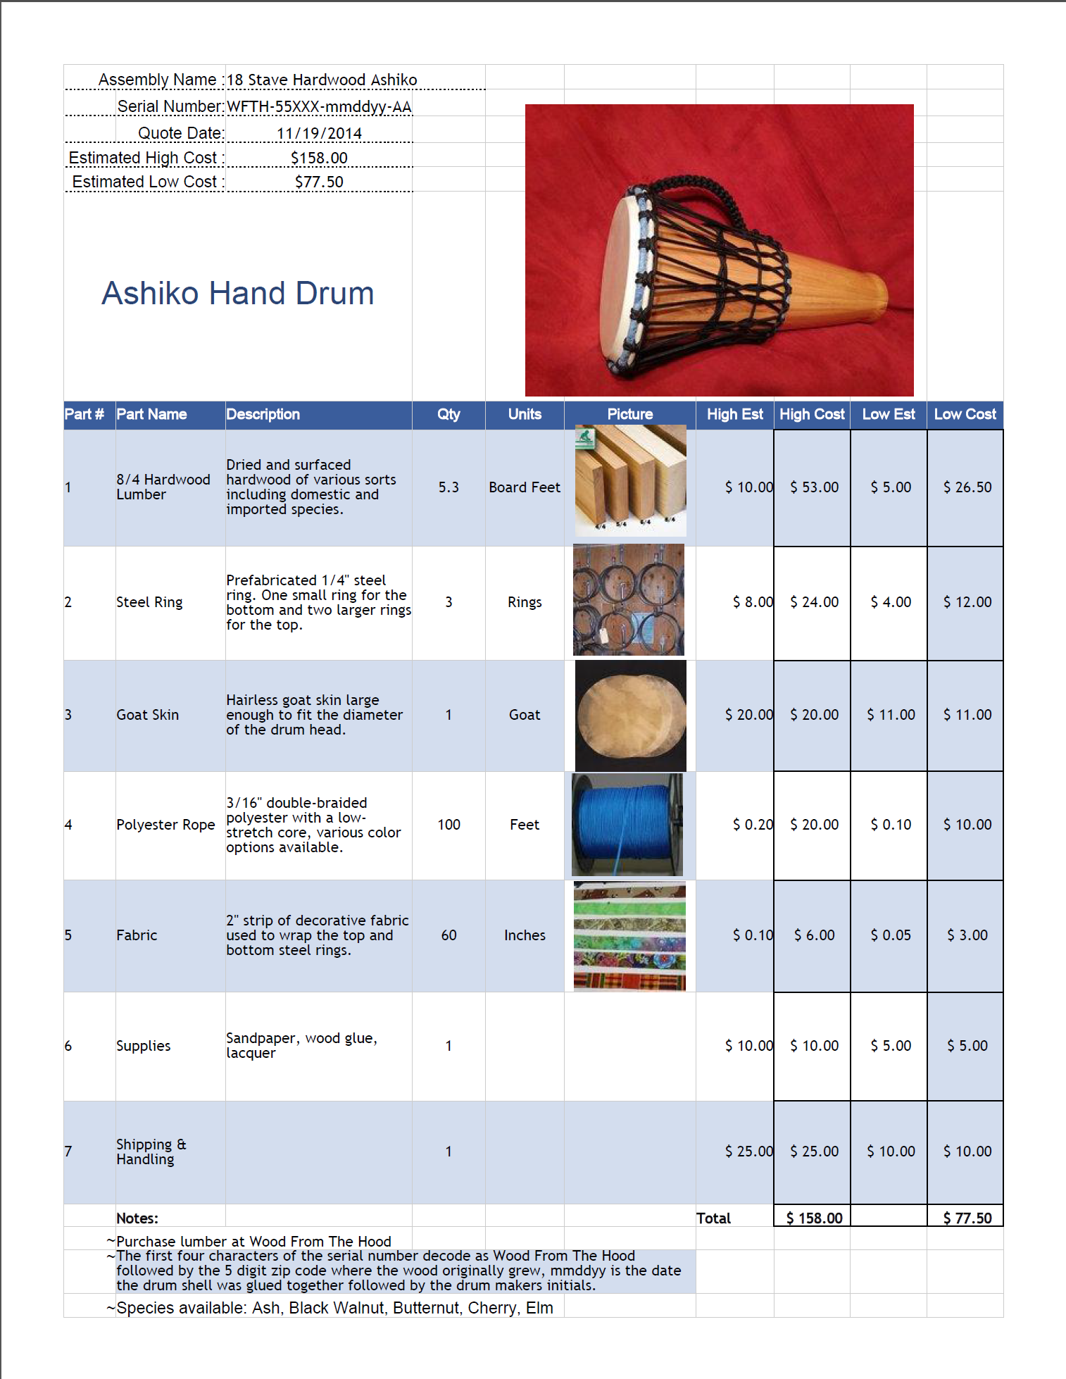
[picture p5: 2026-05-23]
docs/Ashiko Makers Club/Ashiko/BOM.PNG

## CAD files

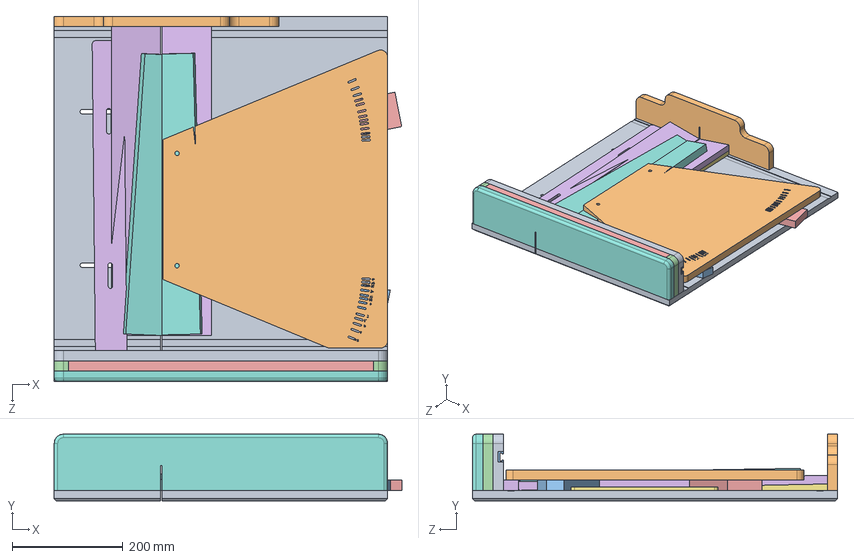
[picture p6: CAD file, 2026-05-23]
CAD/CNC Sled/Segmetor Sled Assembly.SLDASM
628.9 x 120.7 x 660.4 mm
Sled Bottom
Sled Rear A
Sled Rear B
Sled Front
Sliding Track
Sled Rear Side x 2
Sled Rear Top
Taper Wedge - 10 degree 18 stave shell x 2
Compound Taper Wedge Corrector x 2
3x20 Stave x 2

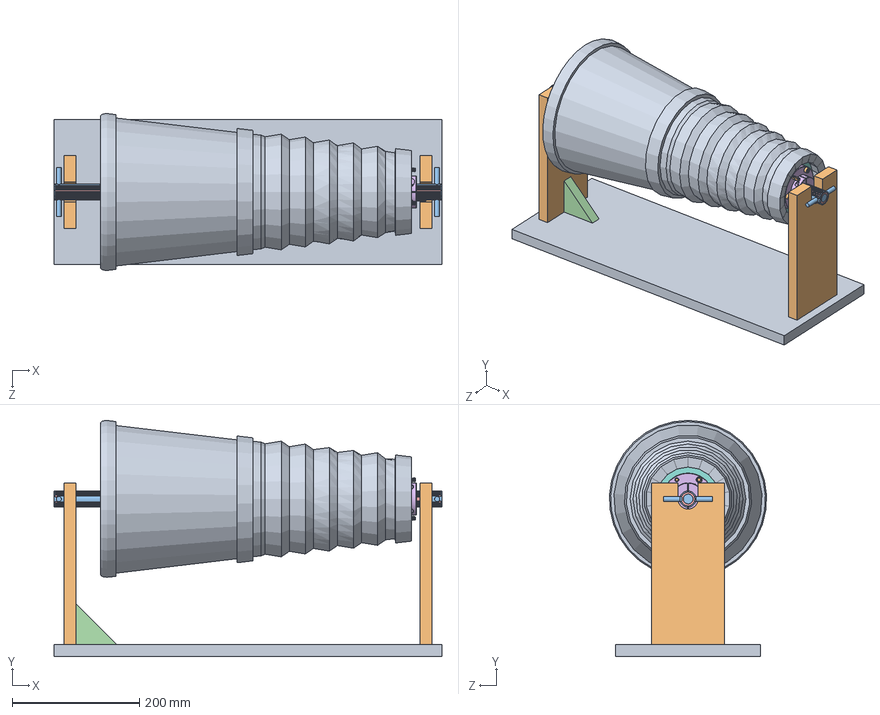
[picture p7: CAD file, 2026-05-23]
docs/Ashiko Makers Club/Ashiko Drums/Finishing Jig.SLDASM
609.6 x 371.2 x 246.8 mm
Base Board
Dowel Holder x 2
Dowel
Rib
9684T400 x 2
Large Block of Wood
Small Block of Wood
Ashiko REV010915
91251A552 x 12
91525A120 x 12
90715A125 x 6

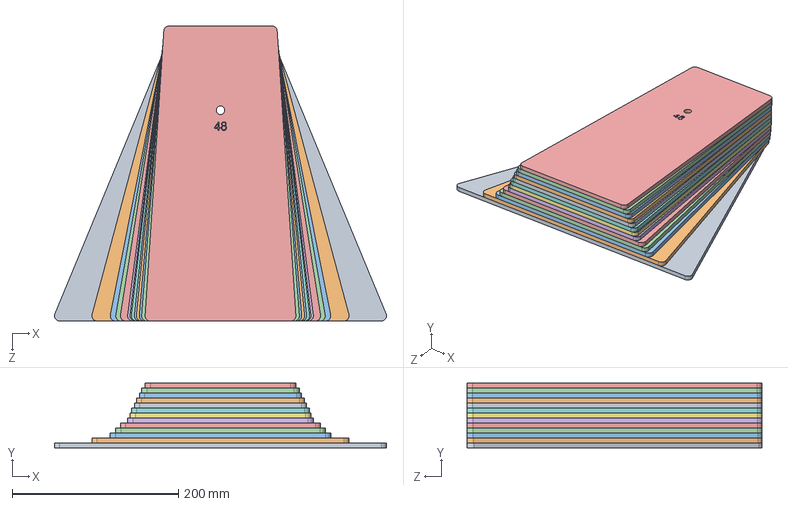
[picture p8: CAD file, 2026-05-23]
CAD/CNC Sled/Wedges/Wedge Stack.SLDASM
400.0 x 77.9 x 355.6 mm
8 Segment Wedgie
12 Segment Wedgie
16 Segment Wedgie
18 Segment Wedge
20 Segment Wedge
24 Segment Wedgie
26 Segment Wedgie (Alphabet)
27 Segment Wedgie (Alphabet + One)
30 Segment Wedge
32 Segment Wedge
36 Segment Wedgie
40 Segment Wedge
48 Segment Wedgie

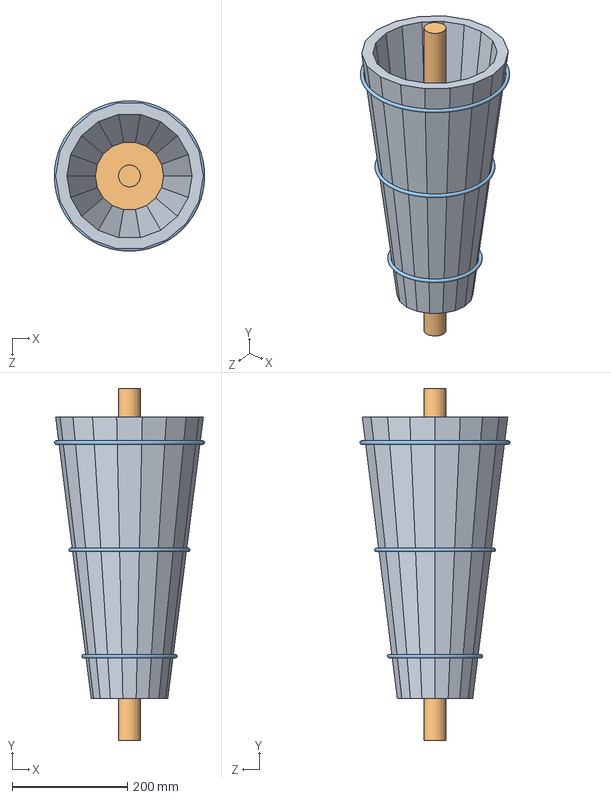
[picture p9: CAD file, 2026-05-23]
docs/Ashiko Makers Club/Shell on Shaft Assembly home.SLDASM
260.3 x 609.6 x 260.2 mm
Ashiko V3 REV010915
Part3^Shell on Shaft Assembly
Part1^Shell on Shaft Assembly

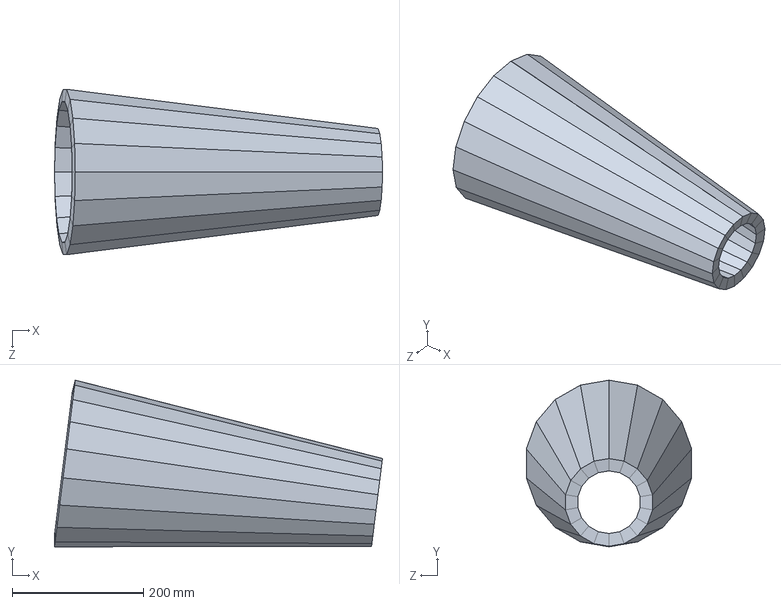
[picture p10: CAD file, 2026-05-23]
docs/Ashiko Makers Club/18 Stave Assembly V4.SLDASM
499.4 x 253.8 x 251.9 mm
19in Stave V3 x 18

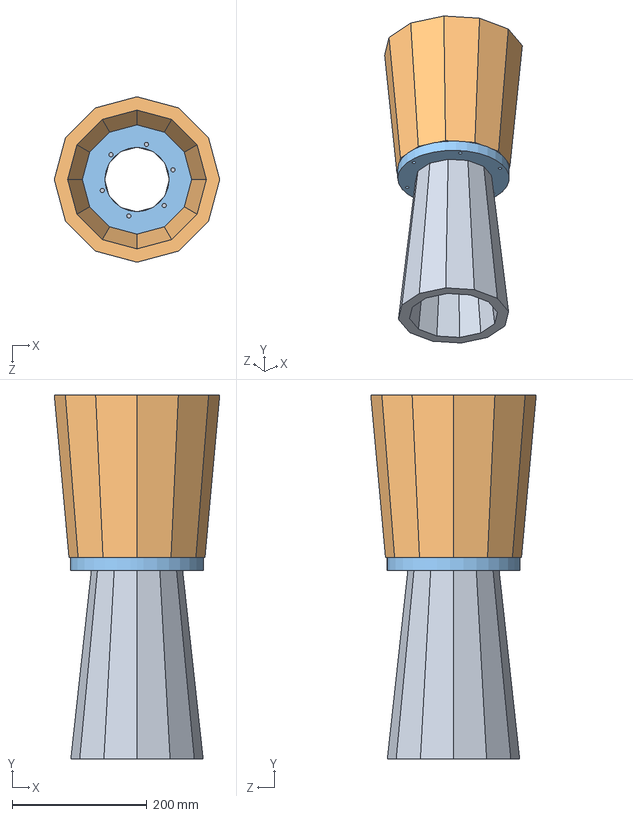
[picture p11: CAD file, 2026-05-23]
docs/Ashiko Makers Club/Djembe/Assem1.SLDASM
245.3 x 539.8 x 245.3 mm
Djembe Bottom REV013015
Djembe Top REV013015
Djembe Joint Plate

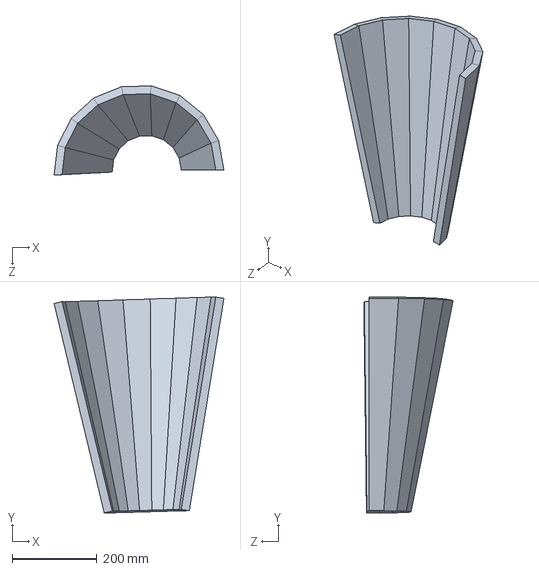
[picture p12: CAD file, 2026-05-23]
CAD/CNC Sled/Universal Tapered Cone Assembly.SLDASM
401.1 x 510.0 x 210.9 mm
3x20 Stave x 9

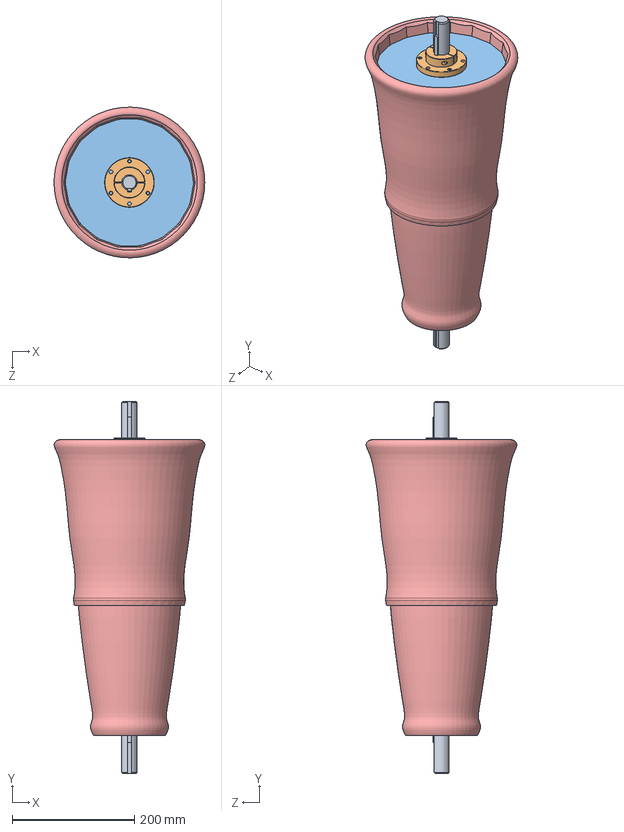
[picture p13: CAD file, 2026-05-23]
docs/Ashiko Makers Club/Shell on Shaft Assembly.SLDASM
246.8 x 609.6 x 246.9 mm
1inch keyed steel drive shaft
9684T400 x 2
Large Wood Block
Small Wood Block

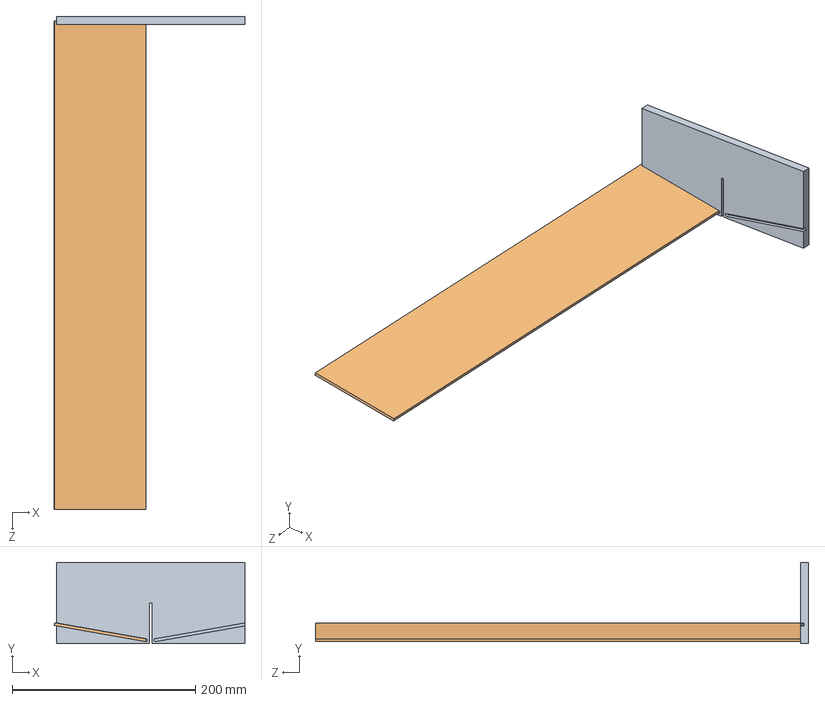
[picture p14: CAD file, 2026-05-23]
CAD/CNC Sled/check what this is.SLDASM
208.3 x 88.9 x 538.6 mm
18 Stave Cartridge
Stave Clamp Plate

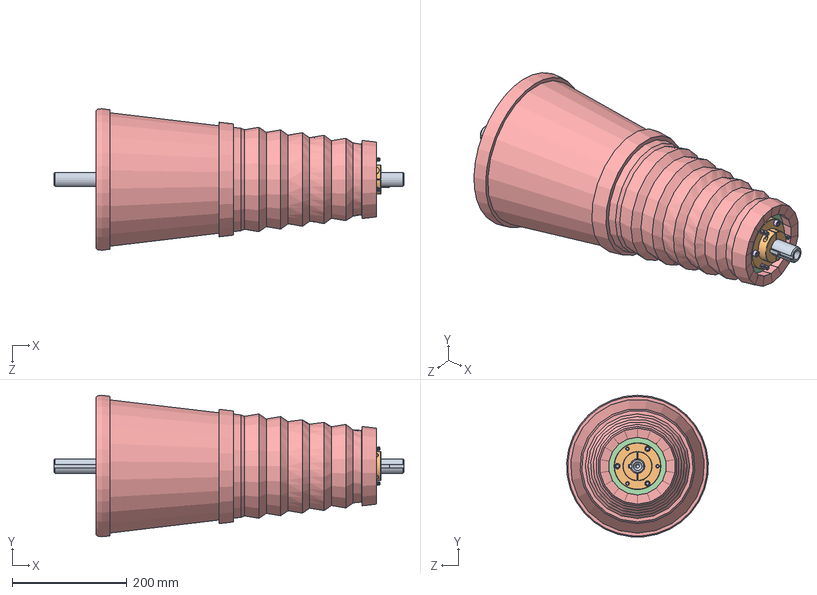
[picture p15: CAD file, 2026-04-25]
docs/Ashiko Makers Club/Ashiko Turning Assembly.SLDASM
609.6 x 246.6 x 246.8 mm
6117K260
9684T400 x 2
Large Block of Wood
Small Block of Wood
Ashiko REV010915
91251A552 x 12
91525A120 x 12
90715A125 x 6

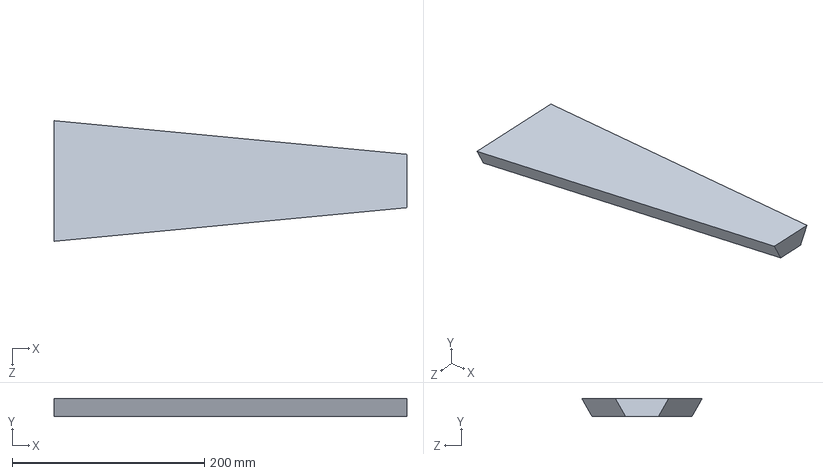
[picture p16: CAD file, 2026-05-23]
CAD/Ashiko Drums/Ashiko Stave.SLDPRT
367.2 x 19.1 x 125.5 mm

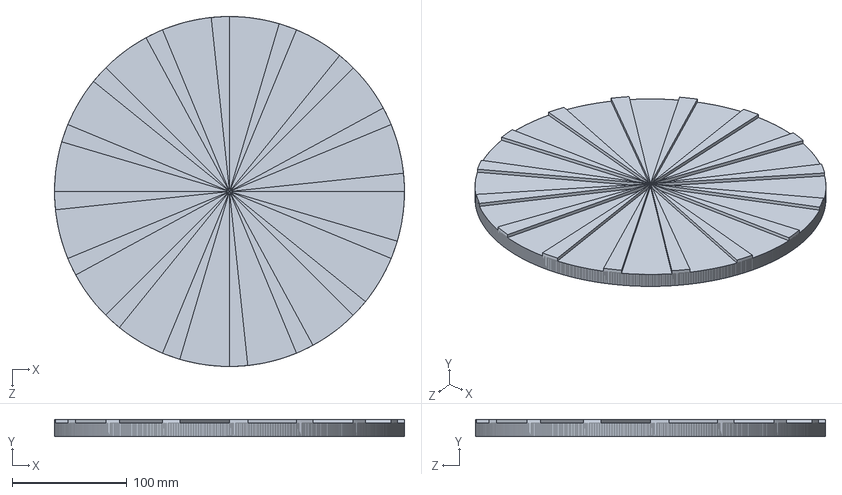
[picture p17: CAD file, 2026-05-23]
CAD/CNC Sled/Open Vessel Spacers/16 Seg 6 degree - Open Segmented Vessel Plate.SLDPRT
304.8 x 15.0 x 304.8 mm

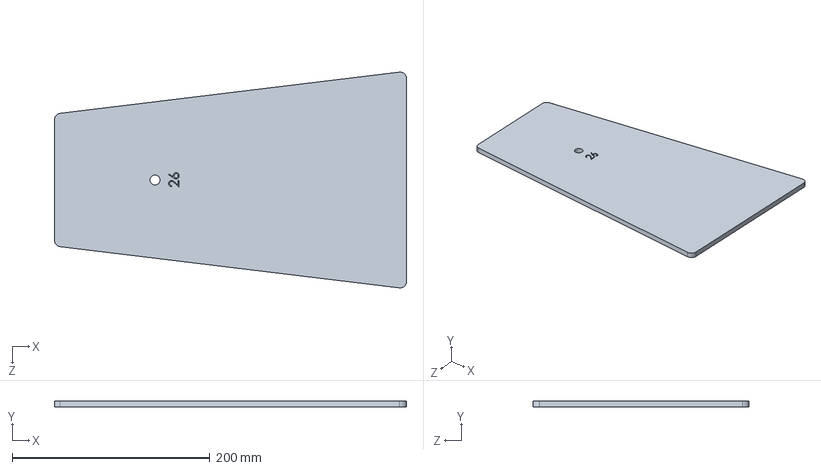
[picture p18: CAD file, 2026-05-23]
CAD/CNC Sled/Wedges/26 Segment Wedgie (Alphabet).SLDPRT
355.6 x 5.99 x 218.0 mm

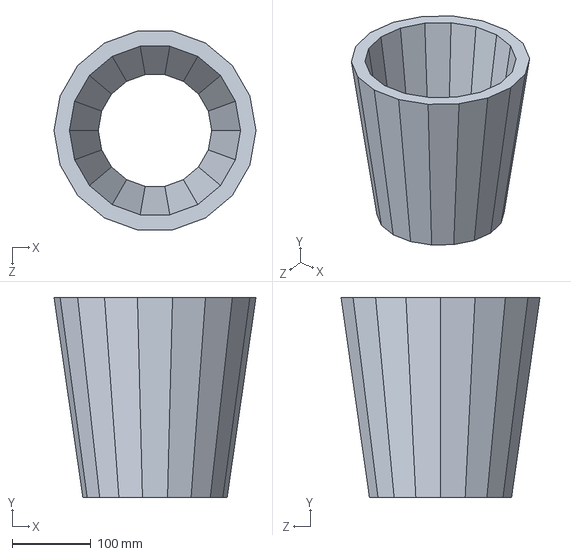
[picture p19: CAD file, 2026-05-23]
docs/Ashiko Makers Club/Djembe/Djembe Top REV012815.SLDPRT
256.0 x 254.0 x 252.1 mm

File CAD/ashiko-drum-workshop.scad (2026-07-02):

// ashiko-drum-workshop.scad — parametric stave-shell envelope master
// =====================================================================
// SOURCE OF TRUTH: build/packet/design.md "Target geometry" table
//   + CAD/drum-body/Ashiko-REV012316.SLDPRT (SolidWorks dimensional authority).
// AUTHORITY: pending_measurement. This is an HONEST ENVELOPE SCAFFOLD, NOT
//   fabrication authority until reviewed against the SolidWorks masters and
//   the 2015 workshop drawings.
//
// SCOPE / BOUNDARY (per V5 percussion addendum):
//   - Models the staved truncated-cone SHELL ENVELOPE + head ring + stave-count
//     facets parametrically, so the overall geometry traces to the design table.
//   - The TUNING-SENSITIVE compound-miter stave cut (miter + bevel derived from
//     taper half-angle, the bearing-edge lathe profile, and the rope-mali lug
//     field) are HAND-REFINED regions and are intentionally OUT OF SCOPE here;
//     they live in the SolidWorks parts and drawings/Stave-Cutting-Process.pdf.
//   - foot_od is an ASSUMPTION (not in the design table) — see comment below.
//
// Render check: openscad -o /tmp/ashiko-drum-workshop-check.stl this-file  (exit 0)
// =====================================================================

/* [Shell — from design.md Target geometry, Standard variant] */
stave_count      = 18;     // design.md: "Stave count 18" (Workshop drawings)
head_od_mm       = 279;    // design.md: Shell OD at head 279 mm (11 in), Standard
shell_height_mm  = 610;    // design.md: Shell height 610 mm (24 in)
stave_bevel_deg  = 10;     // design.md: 10 deg per face (20 deg included), n=18
head_dia_mm      = 254;    // design.md: Head diameter (soaked, mounted) 254 mm (10 in)
wall_mm          = 16;     // ASSUMPTION: nominal stave wall ~16 mm (0.63 in);
                           //   not tabulated — pending measurement of SLDPRT.

/* [Taper — ASSUMPTION, not in design.md] */
// The ashiko is a truncated cone narrowing toward the foot. The design table
// gives ONLY the head OD; the foot OD is not tabulated. Modeled as a parameter,
// clearly marked assumption, so the envelope is honest and reviewable.
foot_od_mm       = 190;    // ASSUMPTION (~0.68 x head OD). PENDING MEASUREMENT.

/* [Maple variant — design.md] */
// head_od_mm = 292; head_dia_mm = 267;  // 11.5 in shell / 10.5 in head

/* [Render] */
$fn = 160;
explode = 0;               // set >0 to lift the head ring for an exploded view

// Derived (formulas, not baked values) ------------------------------
stave_face_width_mm = PI * head_od_mm / stave_count;  // design.md "Computed: pi*D/n"
head_r  = head_od_mm / 2;
foot_r  = foot_od_mm / 2;

// Staved shell as a faceted truncated cone (n = stave_count facets) -------
module shell_outer() {
    cylinder(h = shell_height_mm, r1 = foot_r, r2 = head_r, $fn = stave_count);
}
module shell() {
    difference() {
        shell_outer();
        // inner cavity offset by nominal wall thickness
        translate([0, 0, -1])
            cylinder(h = shell_height_mm + 2,
                     r1 = foot_r - wall_mm, r2 = head_r - wall_mm,
                     $fn = stave_count);
    }
}

// Head bearing ring (goatskin mounts flush to shell OD) ------------------
head_ring_h = 22;  // ASSUMPTION: bearing-edge band height; pending measurement
module head_ring() {
    difference() {
        cylinder(h = head_ring_h, r = head_r);
        translate([0, 0, -1]) cylinder(h = head_ring_h + 2, r = head_dia_mm / 2);
    }
}

// One representative stave face (illustrative, NOT the miter-cut solid) ---
module stave_marker() {
    // thin vertical rib on the outer face to visualize stave_count / width
    a = 360 / stave_count;
    rotate([0, 0, a/2])
        translate([head_r - 1, -stave_face_width_mm/2, 0])
            cube([2, stave_face_width_mm * 0.9, shell_height_mm]);
}

// Assembly --------------------------------------------------------------
module ashiko_assembly() {
    color("Peru") shell();
    for (i = [0 : stave_count - 1])
        rotate([0, 0, i * 360 / stave_count]) color("SaddleBrown") stave_marker();
    translate([0, 0, shell_height_mm + explode * 40])
        color("Tan") head_ring();
}

ashiko_assembly();

// echo derived values for review
echo(str("stave_face_width_mm = ", stave_face_width_mm, " (pi*", head_od_mm, "/", stave_count, ")"));

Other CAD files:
docs/Ashiko Makers Club/Djembe/Whole Stave Sketch.SLDPRT
docs/Ashiko Makers Club/Large Block of Wood.SLDPRT
docs/Ashiko Makers Club/Spokes/16 Spoke.SLDPRT
docs/Ashiko Makers Club/To Print/Front Piece V4.STL
CAD/CNC Sled/18 Stave Cartridge.SLDPRT
CAD/CNC Sled/3x20 Stave.SLDPRT
CAD/CNC Sled/Ashiko Stave REV012316.SLDPRT
CAD/CNC Sled/Compound Taper Wedge Corrector.SLDPRT
CAD/CNC Sled/CrossCut Arm A.SLDPRT
CAD/CNC Sled/CrossCut Arm B.SLDPRT
CAD/CNC Sled/Drawings/CrossCut Arm A.SLDDRW
CAD/CNC Sled/Drawings/CrossCut Arm B.SLDDRW
CAD/CNC Sled/Drawings/Taper Arm.SLDDRW
CAD/CNC Sled/Sled Bottom.SLDPRT
CAD/CNC Sled/Sled Front.SLDPRT
CAD/CNC Sled/Sled Rear A.SLDPRT
CAD/CNC Sled/Sled Rear B.SLDPRT
CAD/CNC Sled/Sled Rear Side.SLDPRT
CAD/CNC Sled/Sled Rear Top.SLDPRT
CAD/CNC Sled/Sliding Track - Short.SLDPRT
CAD/CNC Sled/Sliding Track.SLDPRT
CAD/CNC Sled/Stave Clamp Plate.SLDPRT
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

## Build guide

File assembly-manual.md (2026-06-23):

# Ashiko Drum-Building Workshop — Assembly Manual

This manual documents the eight-stage build process used in the 2015 workshop.
Tolerances reference the acoustic validation checklist at `reference/acoustic-validation-checklist.md`.
SolidWorks CAD authority is in `CAD/`; stave-cut geometry is in `CAD/CNC Sled/`.

---

## Stage 1 — Lumber sourcing and stave-draft

1. Calculate board feet per drum: 4 bd-ft for a standard cherry drum (18 staves × 660 mm × 50 mm × 25 mm rough).
2. Buy in bulk for all builders to capture volume discounts (reduced cost from ~$135 to ~$78/drum in 2015).
3. Execute the stave draft: distribute boards across drums to give each drum a balanced wood mix.
   See `BOM/Stave-Draft-Rounds-1-7.pdf` for the actual 2015 draft spreadsheet.

## Stage 2 — Ripping to rough width

1. Set the table saw fence to rough stave width (≈55 mm for 279 mm shell; allows for bevel cleanup).
2. Rip all boards for a single drum before moving to the next to minimize setup changes.
3. Cross-cut stave blanks to rough length (660 mm; final trim to 610 mm after shape cleanup).

## Stage 3 — Compound miter cuts (table-saw sled)

**Reference:** `skills/stave-construction-compound-miter.md`, `drawings/Stave-Cutting-Process.pdf`

1. Set up the compound miter sled (`CAD/CNC Sled/`) — verify bevel angle (10°) against reference gauge.
2. For each stave: bevel both long faces using the sled fence, then miter-cut both ends.
3. Dry-fit all 18 staves into a ring before glue-up. Accept only if: all joints close cleanly, no more than 0.5 mm gap at any joint, and the ring holds its shape without clamps.
4. Label each stave with its position number in the ring (see `drawings/Stave-Labels-Avery-5160.pdf`).

## Stage 4 — Two-half glue-up

**Open time: ~10 min. Have all materials staged before opening glue.**

1. Divide 18 staves into two half-rounds of 9 staves each (positions 1–9, positions 10–18).
2. Apply Titebond III to both mating faces of every joint in one half-round.
3. Rope-clamp each half-round with cauls (`build/packet/cut-list.csv` CAUL-HALF) and tighten.
4. Allow 2 hours minimum before removing clamps; 24 hours before mating the halves.
5. Repeat for the second half-round.
6. Glue the two half-rounds together in a single seating pass; verify ring geometry before glue sets.
7. Allow 24 hours full cure before any lathe work.

## Stage 5 — Lathe turning

**Reference:** `CAD/lathe-fixture/Ashiko-Turning-Assembly.SLDASM`

1. Mount the keyed steel drive shaft (V2 revision) in the lathe headstock taper. Verify no axial play.
2. Seat the drum body on the cone adapter; tighten collar flange. Rotate by hand first — confirm no wobble.
3. Set lathe to 300–500 RPM. Stand to the side of headstock for the first few rotations.
4. Turn the exterior to final OD (279 mm standard / 292 mm maple variant). Measure with inside calipers.
5. Turn the bearing edge — radius ≤ 1 mm, flush, no proud glue.
6. Final out-of-round check: < 2 mm variation across perpendicular diameters.

## Stage 6 — Sanding and finishing

1. Sand exterior progressively: 80 → 120 → 180 → 220 grit.
2. Blow out dust between grits.
3. Apply two coats Tung oil (Waterlox or equivalent); allow full cure per manufacturer spec.
4. Apply two coats spray lacquer; sand lightly with 400 grit between coats.
5. Final wipe-down with tack cloth before heading.

## Stage 7 — Ropework

1. Bend head hoop to shell OD ± 1 mm; confirm fit before soaking head.
2. Soak goatskin head 15–20 minutes in room-temperature water; check for full flexibility.
3. Center head over hoop; wrap and pin with temporary ties.
4. Lace rope in mali-weave pattern from top hoop to bottom anchor.
5. Alternately tighten opposite pairs of laces to draw head down evenly.
6. Allow head to dry completely under initial tension before final tuning.

## Stage 8 — Final tuning and acceptance

1. After head has dried at initial tension (~12–24 hours), re-tension all laces evenly.
2. Use a tuning mallet or hand technique to check tone uniformity around the head circumference.
3. Record observed pitch (Hz + note name) in `validation.csv` if a chromatic tuner is available.
4. Acceptance criteria per `reference/acoustic-validation-checklist.md`:
   - Head seats flat without rocking (no out-of-round gap at edge)
   - Tone consistent within ±½ step at 4 quadrants of the head
   - No creak or movement at glue lines under hand tension

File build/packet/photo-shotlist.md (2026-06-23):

# Ashiko Drum-Building Workshop — Photo Shotlist

## Workshop archive photos (already captured — 2015)

The following photos already exist in `images/` and document the January–February 2015 workshop:
- `01-early-build.jpg` / `01b-early-build.jpg` — early build stages
- `02-workshop-feb14.jpg` / `02b-workshop-feb15.jpg` — group workshop sessions
- `03-tony-stave-set.jpg` — stave set layout before glue-up
- `04-lathe-turning-mike.jpg` — lathe turning in action
- `05-glue-up-cherry-staves.jpg` / `05b-glue-up-clamping.jpg` / `05c-glue-up-finished-bodies.jpg` — glue-up stages

2021 solo build (Ashiko #009 "Mister Zephyr") photos exist in `images/2021-*`.

## Priority re-shoots or new shots needed

### P1 — Hero product shot (priority: HIGH)
A clean three-quarter view of a finished ashiko showing: shell grain, head, and rope lacing.
Current `images/hero-render.png` is a concept render; a real workshop drum photo would be preferred.
Setup: neutral background, side lighting to show grain texture, head tension visible.

### P2 — Stave cross-section close-up
Macro of assembled stave joint at the shell exterior: shows tight glue-line and grain direction.
Supplement to the stave dimension drawing (D1).

### P3 — Sled jig in use (priority: MEDIUM)
Table saw with compound-miter sled in position, stave blank loaded, about to cut.
Documents the sled correctly positioned and operator technique.

### P4 — Lathe fixture mounted
Keyed shaft engaged in lathe headstock, drum body mounted, ready for turning pass.
Confirms correct fixture orientation.

### P5 — Finished drum family shot (priority: MEDIUM)
Multiple finished drums from the workshop together — showing wood variety (cherry, maple, walnut).
Currently no clean multi-drum family photo exists; the glue-up photos show multiple shells.

### P6 — Head mounting sequence (priority: LOW)
Wet goatskin over hoop, rope lacing start, first tension pass, final tuned head.
Adds build documentation for the heading stages currently undocumented photographically.

## Notes

All new photos should be added to `images/` and registered in `visual-output-register.csv`
with authority = `reference_only` unless they document dimensional authority (in which case,
note the dimension being recorded and provide numerical measurement with the photo).

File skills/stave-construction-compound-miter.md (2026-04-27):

---
name: stave-construction-compound-miter
domain: fabrication geometry
description: |
  Convert a target drum-shell geometry into stave width, bevel, and repeatable
  cut logic for a table-saw or comparable fixture-driven workflow.
status: validated through a 16-drum ashiko workshop and later solo builds
canonical-location: tonykoop/ashiko-drum-workshop/skills/stave-construction-compound-miter.md
also-referenced-from:
  - tonykoop/ashiko-drum-workshop/SKILLS.md
  - tonykoop/ashiko-drum-workshop/README.md
  - tonykoop/djembe/README.md
  - tonykoop/dundun/README.md
provenance: |
  Derived from Morgan Drums practice and formalized through the January 2015
  ashiko workshop documented in this repository.
audience: human (builders, engineers) + agent
maintainer: Tony Koop
license: CC-BY 4.0
---

# Stave Construction Compound Miter

> *Reduce a round or tapered shell to a set of repeatable stave cuts that ordinary shop tools can actually make.*

## When to use this skill

Use this when:

- the shell is built from repeated wooden staves
- the geometry is cylindrical or conical enough that one cut strategy can describe the whole shell or a shell segment
- reproducibility matters as much as the final shape

## Core method

1. Start with the target shell diameter and stave count.
2. Compute the per-stave width from circumference divided by count.
3. Compute the mating bevel angle from the number of staves.
4. Decide whether the shell is constant-angle, single-taper, or variable-profile.
5. If the profile changes along height, decide whether to segment the body, curve the stave, or rough-build then turn to shape later.

## What this skill captures

- Geometry should make the shop process easier, not merely prettier on paper.
- Jigs and fixtures absorb operator variance.
- Cylinders and simple cones are easy cases; goblet forms are where the method gets interesting.
- Stave construction is one of the main bridges between my instrument repos and my broader fabrication work.

## Failure modes I watch for

- Using the right bevel with the wrong stave width and blaming glue-up when the math is the problem.
- Forgetting that a variable-profile drum cannot be solved by a single constant-angle cut all the way up the stave.
- Designing a cut sequence that works for one builder and collapses when eight people try it in parallel.

## Cross-references

- [`ashiko-drum-workshop/README.md`](../README.md)
- [`djembe`](https://github.com/tonykoop/djembe)
- [`dundun`](https://github.com/tonykoop/dundun)

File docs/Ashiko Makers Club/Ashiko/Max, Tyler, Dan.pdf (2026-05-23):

Max
Okray

Max
Okray

Max
Okray

Max
Okray

Max
Okray

Max
Okray

Max
Okray

Max
Okray

Max
Okray

Max
Okray

Max
Okray

Max
Okray

Max
Okray

Max
Okray

Max
Okray

Max
Okray

Max
Okray

Max
Okray

Max
Okray

Max
Okray

Tyler
Kilbury

Tyler
Kilbury

Dan
Estenson

Dan
Estenson

Tyler
Kilbury

Tyler
Kilbury

Dan
Estenson

Dan
Estenson

Tyler
Kilbury

Tyler
Kilbury

Dan
Estenson

Dan
Estenson

Tyler
Kilbury

Tyler
Kilbury

Dan
Estenson

Dan
Estenson

Tyler
Kilbury

Tyler
Kilbury

Dan
Estenson

Dan
Estenson

Tyler
Kilbury

Tyler
Kilbury

Dan
Estenson

Dan
Estenson

Tyler
Kilbury

Tyler
Kilbury

Dan
Estenson

Dan
Estenson

Tyler
Kilbury

Tyler
Kilbury

Dan
Estenson

Dan
Estenson

Tyler
Kilbury

Tyler
Kilbury

Dan
Estenson

Dan
Estenson

Tyler
Kilbury

Tyler
Kilbury

Dan
Estenson

Dan
Estenson

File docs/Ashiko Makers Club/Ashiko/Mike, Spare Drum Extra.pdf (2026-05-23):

Spare
Drum
Extra

Spare
Drum
Extra
Spare
Drum
Extra

Spare
Drum
Extra
Spare
Drum
Extra

Spare
Drum
Extra
Spare
Drum
Extra

Spare
Drum
Extra
Spare
Drum
Extra

Spare
Drum
Extra
Spare
Drum
Extra

Spare
Drum
Extra
Spare
Drum
Extra

Spare
Drum
Extra
Spare
Drum
Extra

Spare
Drum
Extra
Spare
Drum
Extra

Spare
Drum
Extra
Spare
Drum
Extra

Spare
Drum
Extra

Spare
Drum
Extra

Spare
Drum
Extra

Mike
Nieland

Mike
Nieland

Mike
Nieland

Mike
Nieland

Mike
Nieland

Mike
Nieland

Mike
Nieland

Mike
Nieland

Mike
Nieland

Mike
Nieland

Mike
Nieland

Mike
Nieland

Mike
Nieland

Mike
Nieland

Mike
Nieland

Mike
Nieland

Mike
Nieland

Mike
Nieland

Mike
Nieland

Mike
Nieland

Spare
Drum
Extra

Spare
Drum
Extra
Spare
Drum
Extra

Spare
Drum
Extra
Spare
Drum
Extra

Spare
Drum
Extra
Spare
Drum
Extra

Spare
Drum
Extra
Spare
Drum
Extra

Spare
Drum
Extra
Spare
Drum
Extra

Spare
Drum
Extra
Spare
Drum
Extra

Spare
Drum
Extra
Spare
Drum
Extra

Spare
Drum
Extra
Spare
Drum
Extra

Spare
Drum
Extra

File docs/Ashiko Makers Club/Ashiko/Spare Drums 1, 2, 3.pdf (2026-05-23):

Spare
Drum
#1

Spare
Drum
#1

Spare
Drum
#2

Spare
Drum
#2

Spare
Drum
#3

Spare
Drum
#3

Spare
Drum
#1

Spare
Drum
#1

Spare
Drum
#2

Spare
Drum
#2

Spare
Drum
#3

Spare
Drum
#3

Spare
Drum
#1

Spare
Drum
#1

Spare
Drum
#2

Spare
Drum
#2

Spare
Drum
#3

Spare
Drum
#3

Spare
Drum
#1

Spare
Drum
#1

Spare
Drum
#2

Spare
Drum
#2

Spare
Drum
#3

Spare
Drum
#3

Spare
Drum
#1

Spare
Drum
#1

Spare
Drum
#2

Spare
Drum
#2

Spare
Drum
#3

Spare
Drum
#3

Spare
Drum
#1

Spare
Drum
#1

Spare
Drum
#2

Spare
Drum
#2

Spare
Drum
#3

Spare
Drum
#3

Spare
Drum
#1

Spare
Drum
#1

Spare
Drum
#2

Spare
Drum
#2

Spare
Drum
#3

Spare
Drum
#3

Spare
Drum
#1

Spare
Drum
#1

Spare
Drum
#2

Spare
Drum
#2

Spare
Drum
#3

Spare
Drum
#3

Spare
Drum
#1

Spare
Drum
#1

Spare
Drum
#2

Spare
Drum
#2

Spare
Drum
#3

Spare
Drum
#3

Spare
Drum
#1

Spare
Drum
#1

Spare
Drum
#2

Spare
Drum
#2

Spare
Drum
#3

Spare
Drum
#3

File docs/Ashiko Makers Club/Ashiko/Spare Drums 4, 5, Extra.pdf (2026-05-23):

Spare
Drum
#4

Spare
Drum
#4

Spare
Drum
#5

Spare
Drum
#5

Spare
Drum
Extra

Spare
Drum
Extra
Spare
Drum
#4

Spare
Drum
#4

Spare
Drum
#5

Spare
Drum
#5

Spare
Drum
Extra

Spare
Drum
Extra
Spare
Drum
#4

Spare
Drum
#4

Spare
Drum
#5

Spare
Drum
#5

Spare
Drum
Extra

Spare
Drum
Extra
Spare
Drum
#4

Spare
Drum
#4

Spare
Drum
#5

Spare
Drum
#5

Spare
Drum
Extra

Spare
Drum
Extra
Spare
Drum
#4

Spare
Drum
#4

Spare
Drum
#5

Spare
Drum
#5

Spare
Drum
Extra

Spare
Drum
Extra
Spare
Drum
#4

Spare
Drum
#4

Spare
Drum
#5

Spare
Drum
#5

Spare
Drum
Extra

Spare
Drum
Extra
Spare
Drum
#4

Spare
Drum
#4

Spare
Drum
#5

Spare
Drum
#5

Spare
Drum
Extra

Spare
Drum
Extra
Spare
Drum
#4

Spare
Drum
#4

Spare
Drum
#5

Spare
Drum
#5

Spare
Drum
Extra

Spare
Drum
Extra
Spare
Drum
#4

Spare
Drum
#4

Spare
Drum
#5

Spare
Drum
#5

Spare
Drum
Extra

Spare
Drum
Extra
Spare
Drum
#4

Spare
Drum
#4

Spare
Drum
#5

Spare
Drum
#5

Spare
Drum
Extra

Spare
Drum
Extra

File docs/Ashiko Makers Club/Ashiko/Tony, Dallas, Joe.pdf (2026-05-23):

Tony
Koop

Tony
Koop

Tony
Koop

Tony
Koop

Tony
Koop

Tony
Koop

Tony
Koop

Tony
Koop

Tony
Koop

Tony
Koop

Tony
Koop

Tony
Koop

Tony
Koop

Tony
Koop

Tony
Koop

Tony
Koop

Tony
Koop

Tony
Koop

Tony
Koop

Tony
Koop

Dallas
Nustvold

Dallas
Nustvold

Dallas
Nustvold

Dallas
Nustvold

Dallas
Nustvold

Dallas
Nustvold

Dallas
Nustvold

Dallas
Nustvold

Dallas
Nustvold

Dallas
Nustvold

Dallas
Nustvold

Dallas
Nustvold

Dallas
Nustvold

Dallas
Nustvold

Dallas
Nustvold

Dallas
Nustvold

Dallas
Nustvold

Dallas
Nustvold

Dallas
Nustvold

Dallas
Nustvold

Joe
Spitzenberger

Joe
Spitzenberger
Joe
Spitzenberger

Joe
Spitzenberger
Joe
Spitzenberger

Joe
Spitzenberger
Joe
Spitzenberger

Joe
Spitzenberger
Joe
Spitzenberger

Joe
Spitzenberger
Joe
Spitzenberger

Joe
Spitzenberger
Joe
Spitzenberger

Joe
Spitzenberger
Joe
Spitzenberger

Joe
Spitzenberger
Joe
Spitzenberger

Joe
Spitzenberger
Joe
Spitzenberger

Joe
Spitzenberger

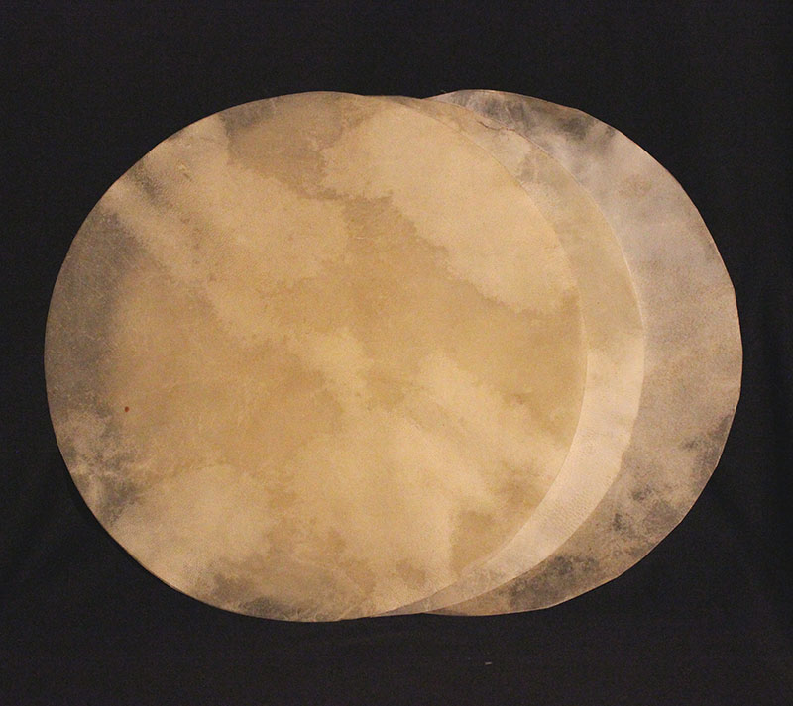
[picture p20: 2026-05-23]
docs/Ashiko Makers Club/Ashiko Drums/1400.jpg

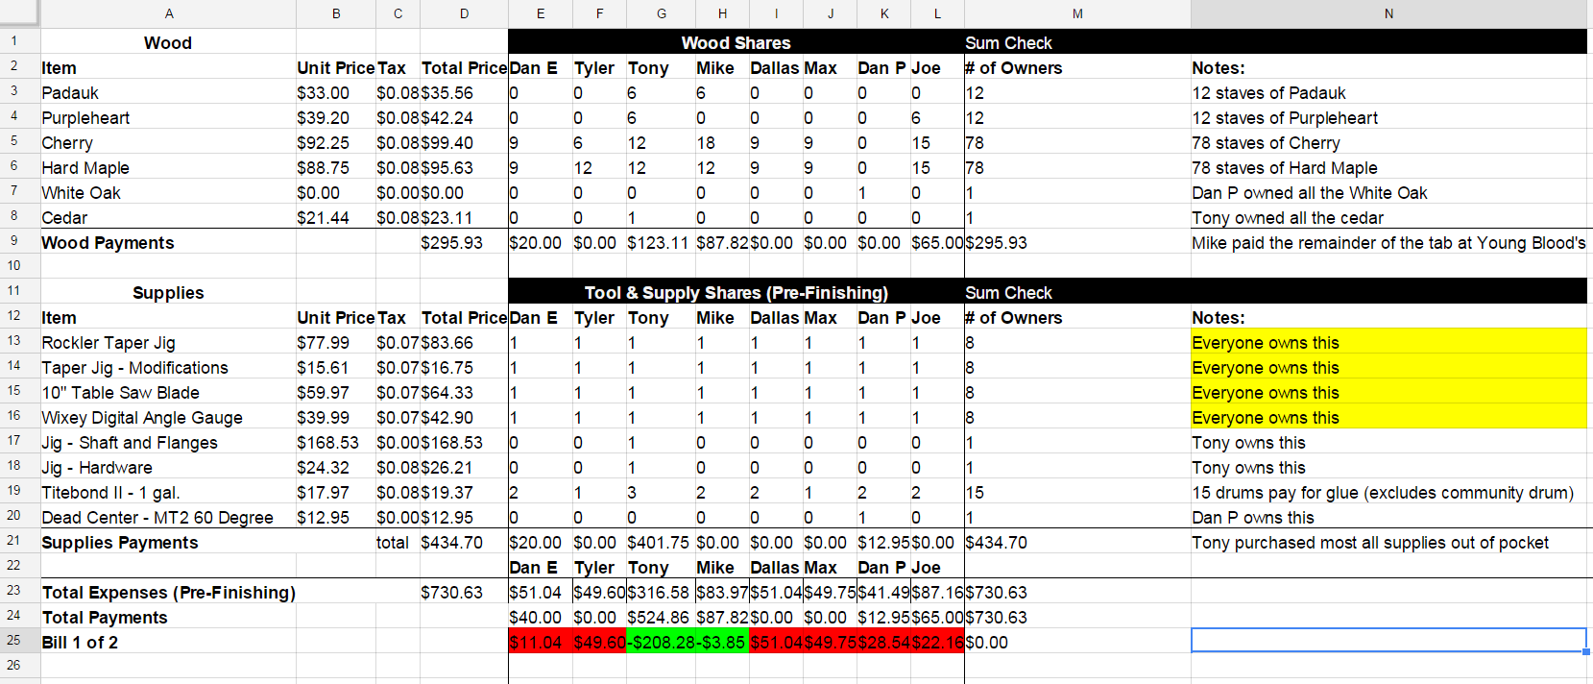
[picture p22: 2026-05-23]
docs/Ashiko Makers Club/Bill 1 of 2.PNG

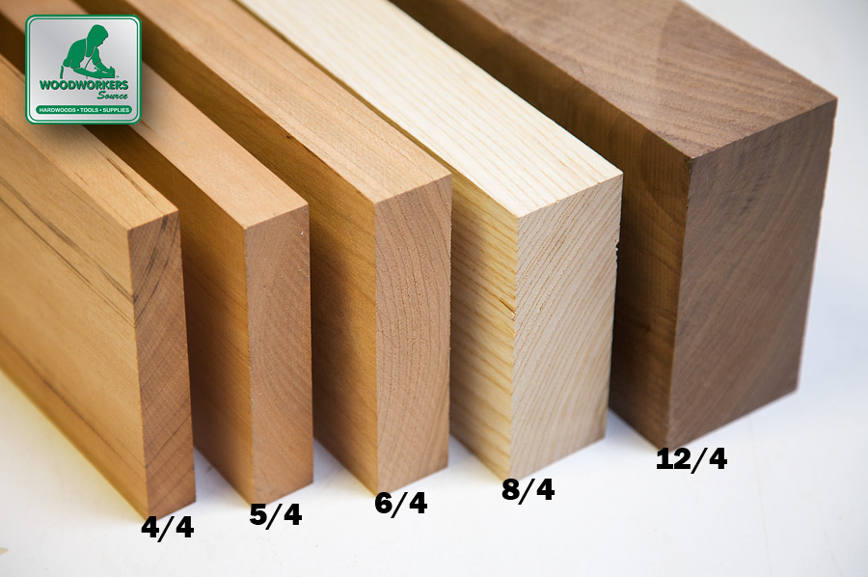
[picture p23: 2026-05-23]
docs/Ashiko Makers Club/Ashiko Drums/lumber_thickness_compared1.jpg

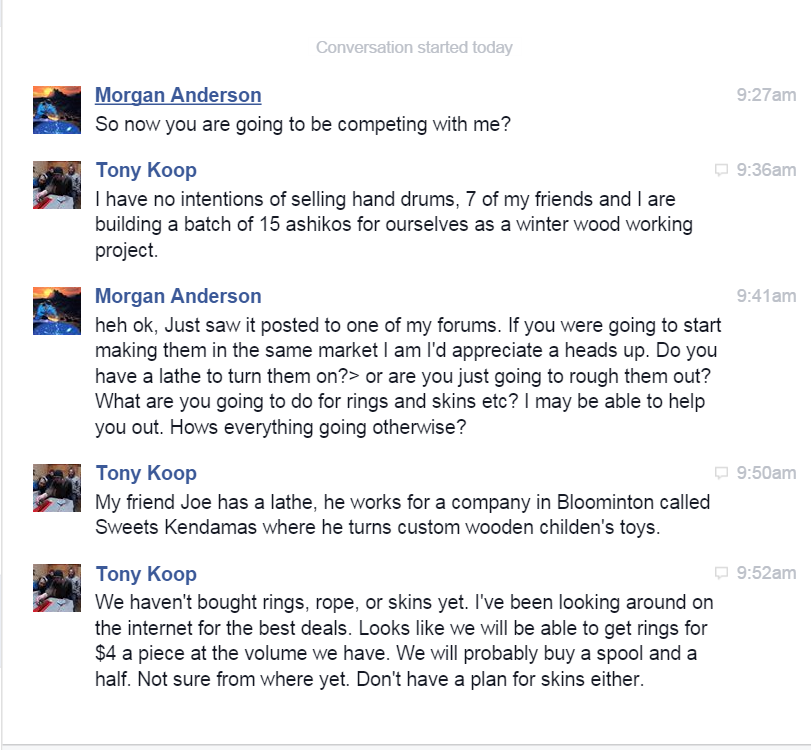
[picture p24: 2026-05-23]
docs/Ashiko Makers Club/Capture.PNG

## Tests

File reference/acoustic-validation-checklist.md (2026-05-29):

# Ashiko Drum — Acoustic Validation Checklist

Acceptance checklist for workshop-built ashiko drums. Use at two checkpoints:
pre-build (before glue-up or before heading) and post-build (after first
tuning). Gates are pass/fail/pending — no partial credit.

This checklist records workshop outcomes against the nominal build targets in
`validation.csv`. It does not substitute for a full acoustic measurement loop;
that requires a measurement microphone and signal chain beyond the scope of
the original 2015 workshop.

---

## Pre-Build Gates (before heading)

### Shell geometry

- [ ] Stave count confirmed (18 standard for this workshop batch).
- [ ] Bevel angle consistent across all staves on a given drum (visual check
  with reference bevel gauge; large variation is a fail).
- [ ] Shell diameter measured at head-bearing surface: within ±3 mm of nominal
  before accepting for heading (nominal 279 mm cherry / 292 mm maple).
- [ ] Shell roundness: out-of-round ≤ 2 mm across any two perpendicular diameters
  at the head-bearing surface. Check with inside calipers.
- [ ] Shell height within ±5 mm of nominal (610 mm standard / 622 mm tall variant).
- [ ] Glue lines at bearing edge flush; no proud glue that would rock the head.

### Head preparation

- [ ] Goatskin head soaked in room-temperature water for 15–20 min.
- [ ] No visible holes, tears, or thin spots in the head membrane before seating.
- [ ] Head diameter at least 25 mm larger than shell bearing-edge OD on each
  side (allows wrap over hoop without pinching).

### Rope and hoop

- [ ] Hoops debarked and any sharp edges sanded before head wrap.
- [ ] Rope type confirmed consistent across all drums in the batch
  (substituting cord diameter or fiber mid-batch changes tuning range and
  sustain character).
- [ ] Rope cut to uniform length per drum; excess bundled and kept with the drum
  for later adjustment.

---

## Post-Build Gates (after first tuning)

### Tuning and pitch

- [ ] Head seated evenly (no low spots where rope pulls unevenly on one side).
- [ ] Fundamental pitch audible by ear: slap tone rings sustain ≥ 1 s in a
  quiet room. If sustain collapses under 0.5 s, check bearing edge and head
  seating.
- [ ] Target pitch range: for a 279 mm cherry shell, fundamental typically
  lands D3–G3 (approximately 147–196 Hz) with a Mali-weave rope system at
  working tension. This is a planning target, not a specification — actual
  pitch depends on head thickness, rope tension, and room humidity.
  **Modeling caveat**: pitch estimates in validation.csv are based on
  generalized membrane-acoustics ratios from similar-diameter instruments;
  they are not derived from physical measurement of these specific 16 drums.
- [ ] Open tone (palm flat on center) clearly lower in pitch than slap tone
  (fingers on edge). If tones are close together, head may be overtensioned.
- [ ] Bass tone (thumb press near center, other hand mutes) rings cleanly.
- [ ] No buzzing or sympathetic rattle from loose hoops, rope, or glue joint.

### Safety and ergonomics

- [ ] Head firmly seated; no audible creak under normal playing pressure.
- [ ] No sharp rope ends exposed above the hoop wrap level.
- [ ] Shell shows no cracking at glue lines after first tuning cycle.
- [ ] Drum sits level on a flat surface without rocking.

---

## Recording Notes

Record outcomes per drum in `validation.csv` columns `observed_pitch_hz`,
`observed_pitch_note`, and `observed_tone_quality`. For 2015 workshop drums
where measurements were not taken, leave those fields as `pending_measurement`.
Any future measurement session should record: tuner or spectrum-analyzer
reading, room temperature, relative humidity, and head age since soaking, so
results can be compared across sessions.

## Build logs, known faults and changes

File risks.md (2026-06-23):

# Ashiko Drum-Building Workshop — Build Risks

## Fabrication risks

### R1 — Stave bevel angle inconsistency (HIGH)
If the table-saw sled is not set to exactly the correct bevel before each cut sequence,
bevel variance across 18 staves accumulates into an out-of-round shell that cannot be
corrected at heading. Mitigation: set the sled against a reference bevel gauge before
each drum's stave batch; verify with a test fit of all 18 dry staves in a ring before glue-up.
The sled CAD (`CAD/CNC Sled/`) and `drawings/Stave-Cutting-Process.pdf` document the
setup procedure.

### R2 — Two-half glue-up timing (MEDIUM)
Titebond III has an open time of approximately 10 minutes. With 9 staves per half-round,
the caul must be positioned and rope-clamped within this window. With first-time builders,
have all materials staged before opening the glue. Do not attempt a full 18-stave
single-pass glue-up.

### R3 — Lathe fixture walk (MEDIUM)
If the keyed drive shaft is not fully seated in the headstock taper, the drum body will
walk axially during turning. This can damage the bearing edge. Check for play before
starting the lathe. The V2 shaft revision (`CAD/lathe-fixture/`) addressed V1 slippage.

### R4 — Head over-soak or under-soak (MEDIUM)
Goatskin soaked less than 12 minutes will not stretch to seat properly over the hoop.
Soaked more than 30 minutes it may weaken and tear on tightening. Aim for 15–20 minutes
in room-temperature water; check for full flexibility before mounting.

### R5 — Out-of-round shell at heading (HIGH)
A shell with OD variance > 2 mm across perpendicular diameters will not seal the head
evenly, causing tone inconsistency and potential head tearing at the out-of-round point.
Lathe-turning the shell to final OD is the primary mitigation; check with inside calipers
before heading.

## Safety risks

### S1 — Compound miter table saw cuts
Cutting 18 staves per drum with two compound miter passes per stave requires full push-stick
technique and positive control of narrow stock against the sled fence. Use featherboards
where possible. Do NOT reach over the blade to retrieve cut stave pieces.

### S2 — Lathe speed selection
Turn drum bodies at the lowest speed that provides stable rotation (typically 300–500 RPM
for a 10–12" shell). Higher speeds increase vibration risk if the body is out of balance.
Stand to the side of the lathe headstock during the first few rotations of each shell.

### S3 — Rope lacing tension
Mali-style rope lacing generates significant radial compression on the shell. Check that
no glue-line gaps opened during final tuning. A gap > 0.5 mm at a load-bearing glue line
is a reject — the shell can split under head tension.

## Provenance notes

- Pitch measurements not recorded for 16 workshop drums (2015). `validation.csv` shows
  nominal geometry only; `observed_pitch_hz` fields are empty.
- The 2021 solo build of Ashiko #009 (Douglas Fir) was not photographed during all stages.
- Segmented-ashiko CAD in `CAD/segmented-ashiko/` is an alternate geometry study, not the
  build authority for the 18-stave workshop drums. Do not use for stave-cut parameters.

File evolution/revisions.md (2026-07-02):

# Revision Register — ashiko-drum-workshop

| Rev | Date | Parent | Delta | Downstream artifacts invalidated |
| --- | --- | --- | --- | --- |
| A | 2026-07-01 | — | Stage 0 intake of current masters (CAD/ashiko-drum-workshop.scad envelope + ashiko-drum-workshop-design-table.xlsx + CAD/drum-body/ SolidWorks parts). | none (no alpha/beta/production artifacts exist yet) |

Stage 0 only. Gate A has not been run; no Alpha compiles, vendor quotes, or production lock exist for this product.

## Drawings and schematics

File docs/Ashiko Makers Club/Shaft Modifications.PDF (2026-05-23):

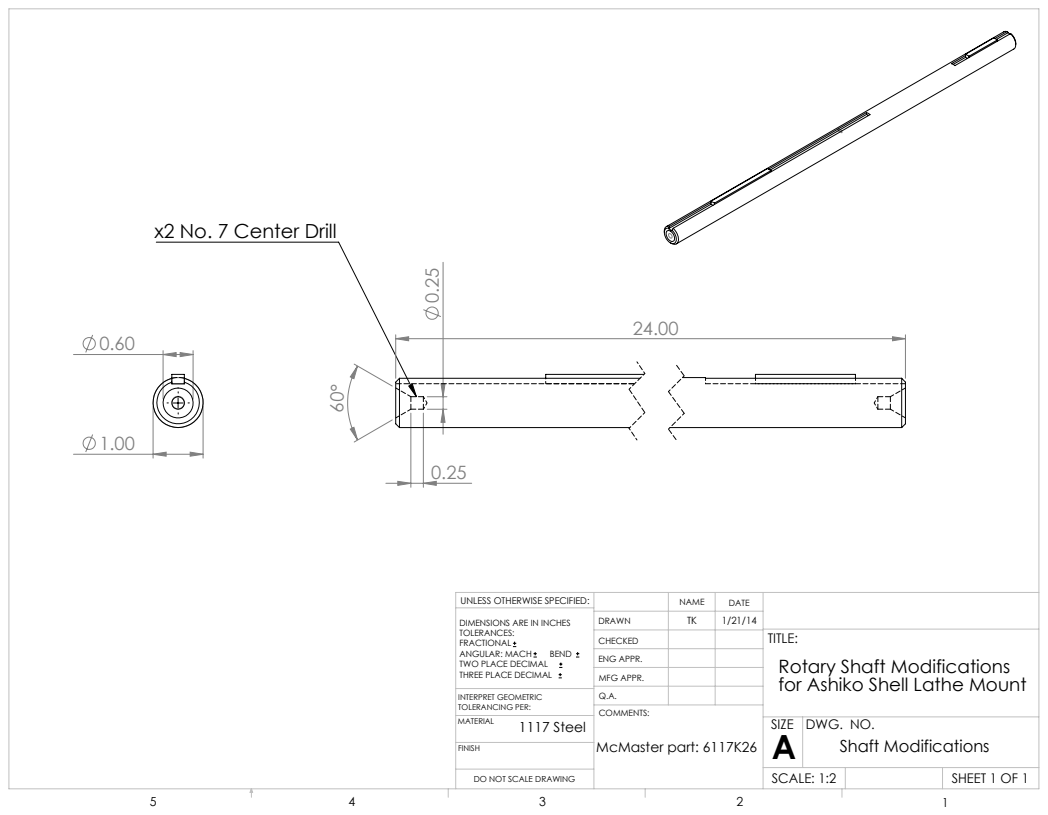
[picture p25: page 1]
SHEET 1 OF 1; SCALE: 1:2; DWG. NO.; MFG APPR.; ENG APPR.; INTERPRET GEOMETRIC TOLERANCING PER:; ANGULAR: MACH; BEND; 1117 Steel; McMaster part: 6117K26

x2 No. 7 Center Drill

UNLESS OTHERWISE SPECIFIED:

DIMENSIONS ARE IN INCHES
TOLERANCES:
FRACTIONAL
TWO PLACE DECIMAL
THREE PLACE DECIMAL

TITLE:
Rotary Shaft Modifications
for Ashiko Shell Lathe Mount
Shaft Modifications

DO NOT SCALE DRAWING

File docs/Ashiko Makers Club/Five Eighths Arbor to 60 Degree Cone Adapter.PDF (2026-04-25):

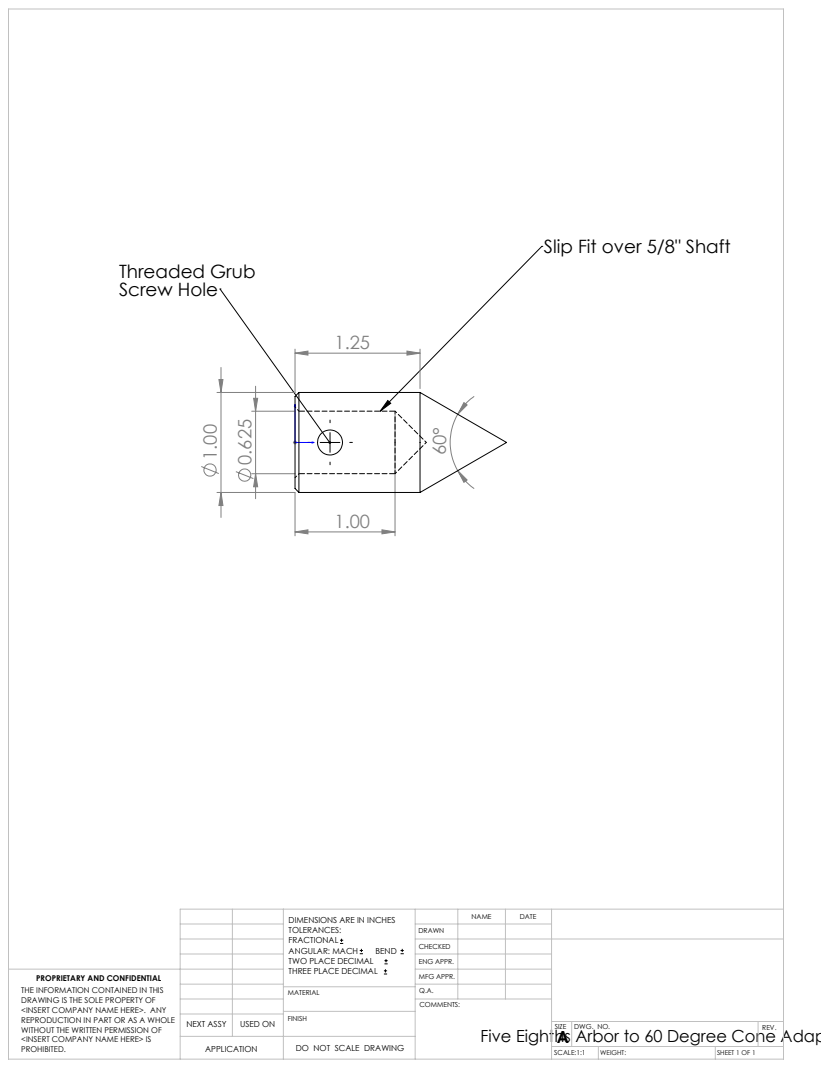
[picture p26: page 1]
Threaded Grub Screw Hole

Slip Fit over 5/8" Shaft

TOLERANCES: FRACTIONAL ANGULAR: MACH BEND TWO PLACE DECIMAL THREE PLACE DECIMAL | | NAME | DATE DIMENSIONS ARE IN INCHES

DRAWN
CHECKED
ENG APPR.

PROPRIETARY AND CONFIDENTIAL THE INFORMATION CONTAINED IN THIS DRAWING IS THE SOLE PROPERTY OF <INSERT COMPANY NAME HERE>. ANY REPRODUCTION IN PART OR AS A WHOLE WITHOUT THE WRITTEN PERMISSION OF <INSERT COMPANY NAME HERE> IS PROHIBITED. | | | MFG APPR.

MATERIAL | Q.A.

COMMENTS:
Five Eighths Arbor to 60 Degree Cone Adapter

NEXT ASSY | USED ON | FINISH

SIZE A | DWG. NO. | REV.

APPLICATION | | DO NOT SCALE DRAWING

SCALE:1:1 | WEIGHT: | SHEET 1 OF 1

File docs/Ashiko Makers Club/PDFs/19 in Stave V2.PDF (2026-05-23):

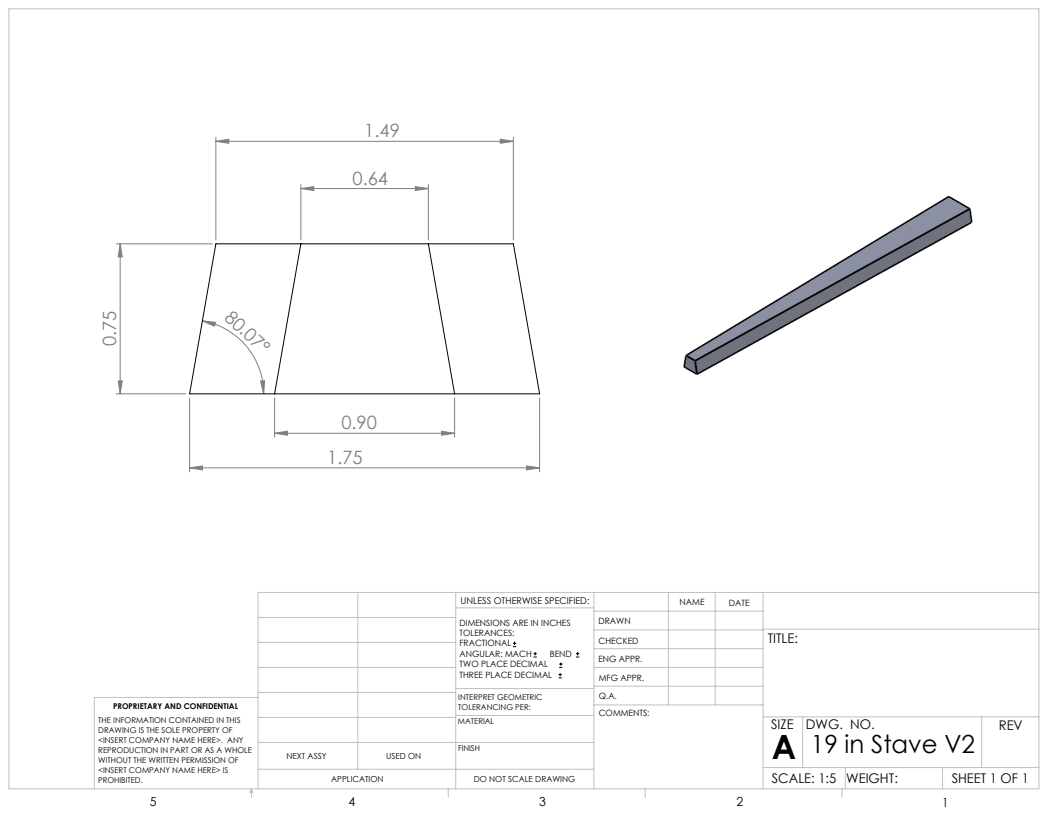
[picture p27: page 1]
19 in Stave V2; SHEET 1 OF 1; SCALE: 1:5 WEIGHT:; DWG. NO.; REV; MFG APPR.; ENG APPR.; INTERPRET GEOMETRIC TOLERANCING PER:; ANGULAR: MACH; BEND; NEXT ASSY; USED ON

UNLESS OTHERWISE SPECIFIED:

DIMENSIONS ARE IN INCHES
TOLERANCES:
FRACTIONAL
TWO PLACE DECIMAL
THREE PLACE DECIMAL

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

DO NOT SCALE DRAWING

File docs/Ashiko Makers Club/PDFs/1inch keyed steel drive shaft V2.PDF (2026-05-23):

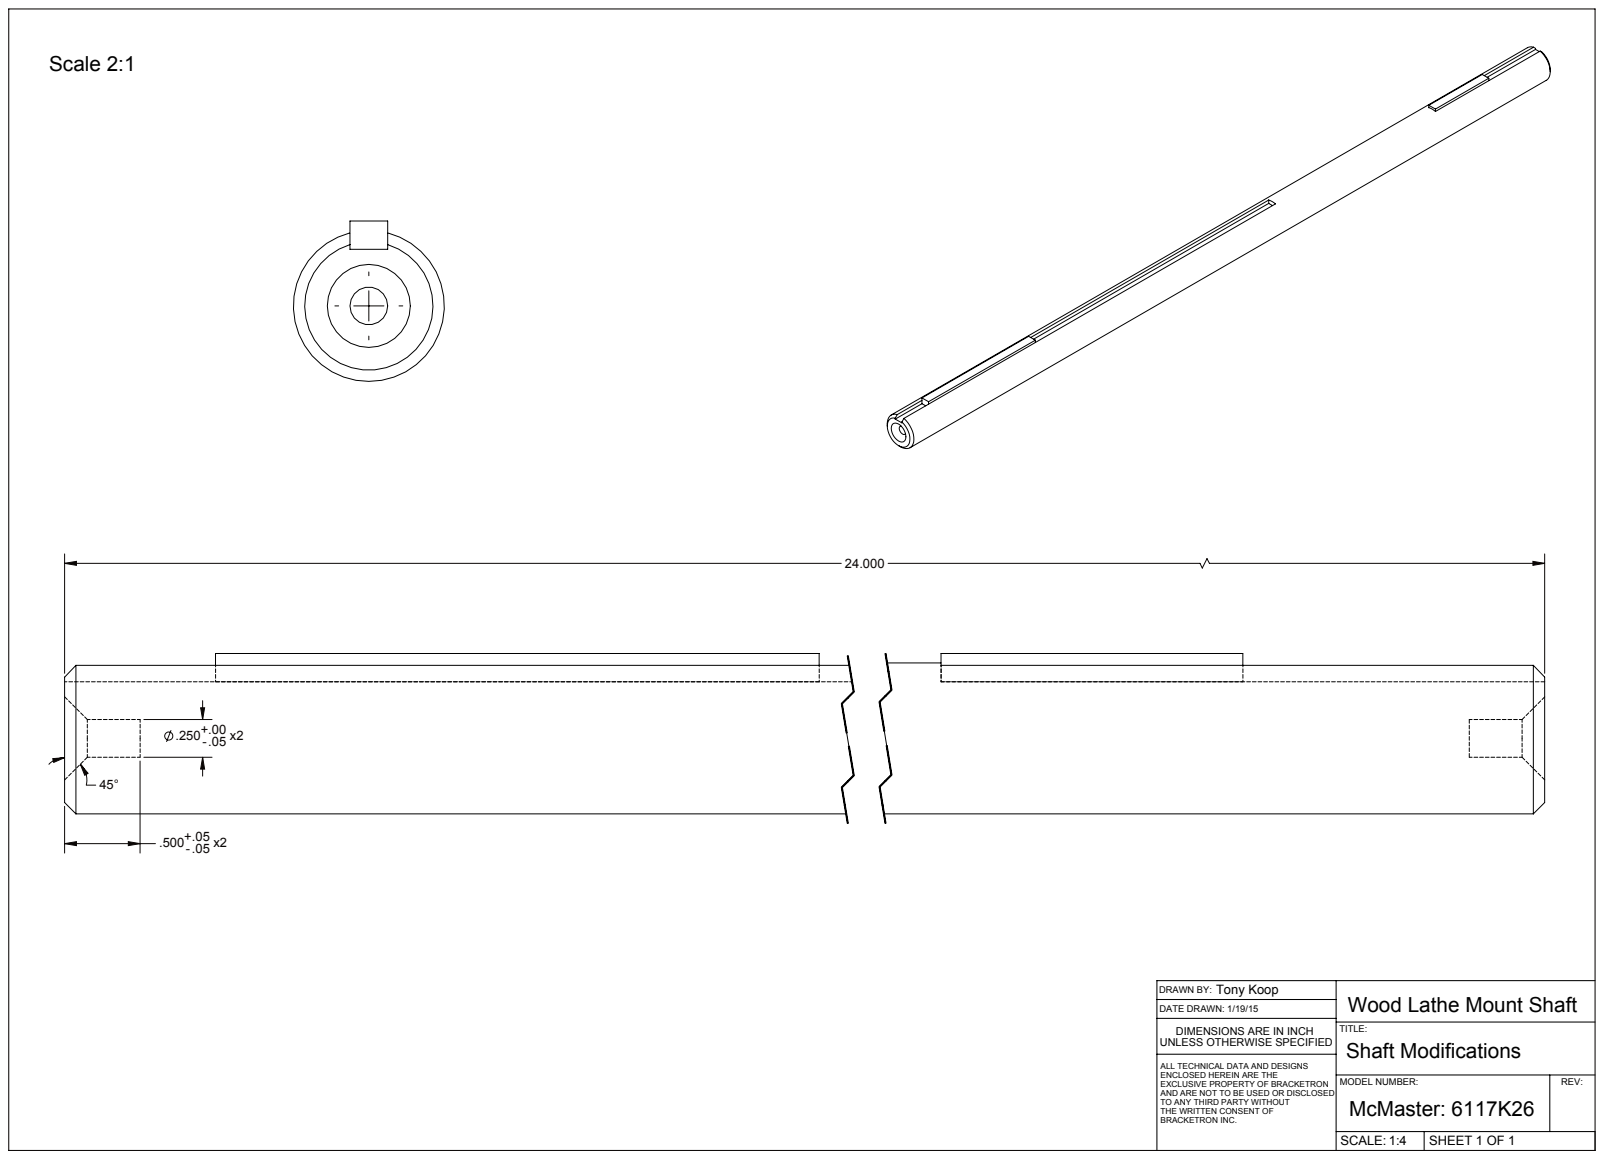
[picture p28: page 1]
Scale 2:1

DRAWN BY: Tony Koop
DATE DRAWN: 1/19/15
DIMENSIONS ARE IN INCH
UNLESS OTHERWISE SPECIFIED

Wood Lathe Mount Shaft
Shaft Modifications

ALL TECHNICAL DATA AND DESIGNS
ENCLOSED HEREIN ARE THE
EXCLUSIVE PROPERTY OF BRACKETRON
AND ARE NOT TO BE USED OR DISCLOSED
TO ANY THIRD PARTY WITHOUT
THE WRITTEN CONSENT OF
BRACKETRON INC.

MODEL NUMBER: McMaster: 6117K26 | REV:

SCALE: 1:4 | SHEET 1 OF 1

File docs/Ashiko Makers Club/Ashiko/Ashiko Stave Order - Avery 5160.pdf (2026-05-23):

# Stave 3

# Stave 4

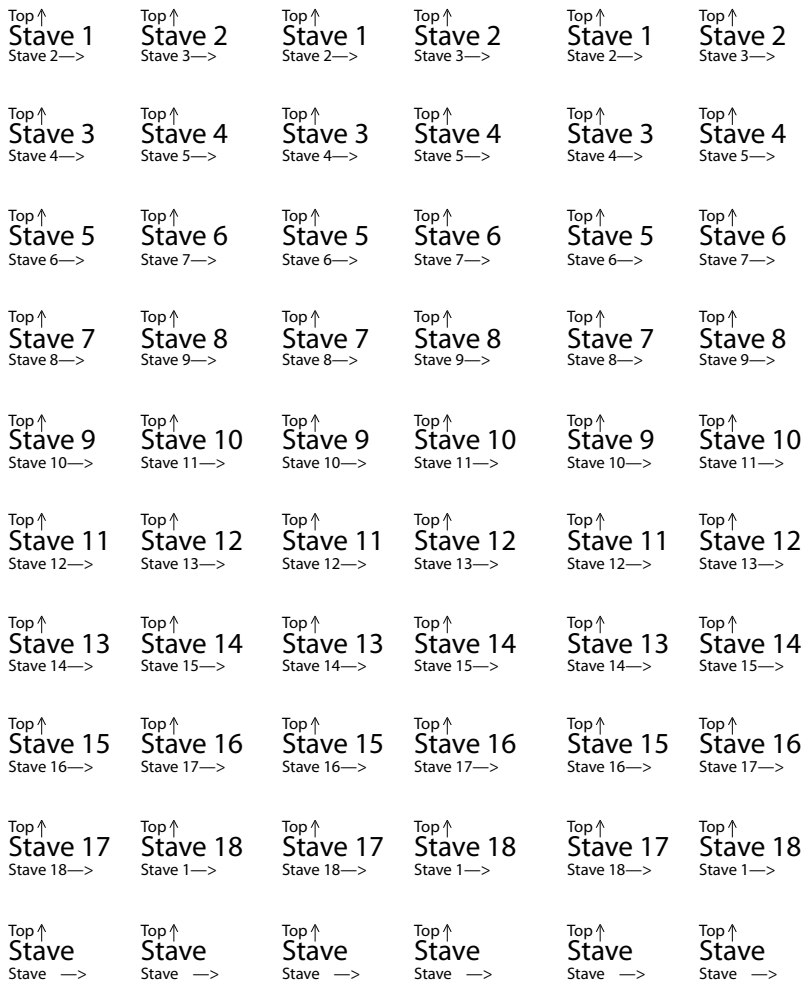
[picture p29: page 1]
Stave 4—>; Top; Stave 5—>; Stave 6—>; Top Stave 5; Stave 7—>; Top Stave 6; Stave 8—>; Top Stave 7; Stave 9—>; Top Stave 8; Stave 10—>; Top Stave 9; Stave 11—>; Top Stave 10; Stave 12—>; Top Stave 11; Stave 13—>; Top Stave 12; Stave 14—>; Top Stave 13; Stave 15—>; Top Stave 14; Stave 16—>; Top Stave 15; Stave 17—>; Top Stave 16; Stave 18—>; Top Stave 17; Stave 1—>; Top Stave 18; Stave —>; Top Stave; Top Stave 3; Top Stave 4; Stave 2—>; Top Stave 1; Stave 3—>; Top Stave 2

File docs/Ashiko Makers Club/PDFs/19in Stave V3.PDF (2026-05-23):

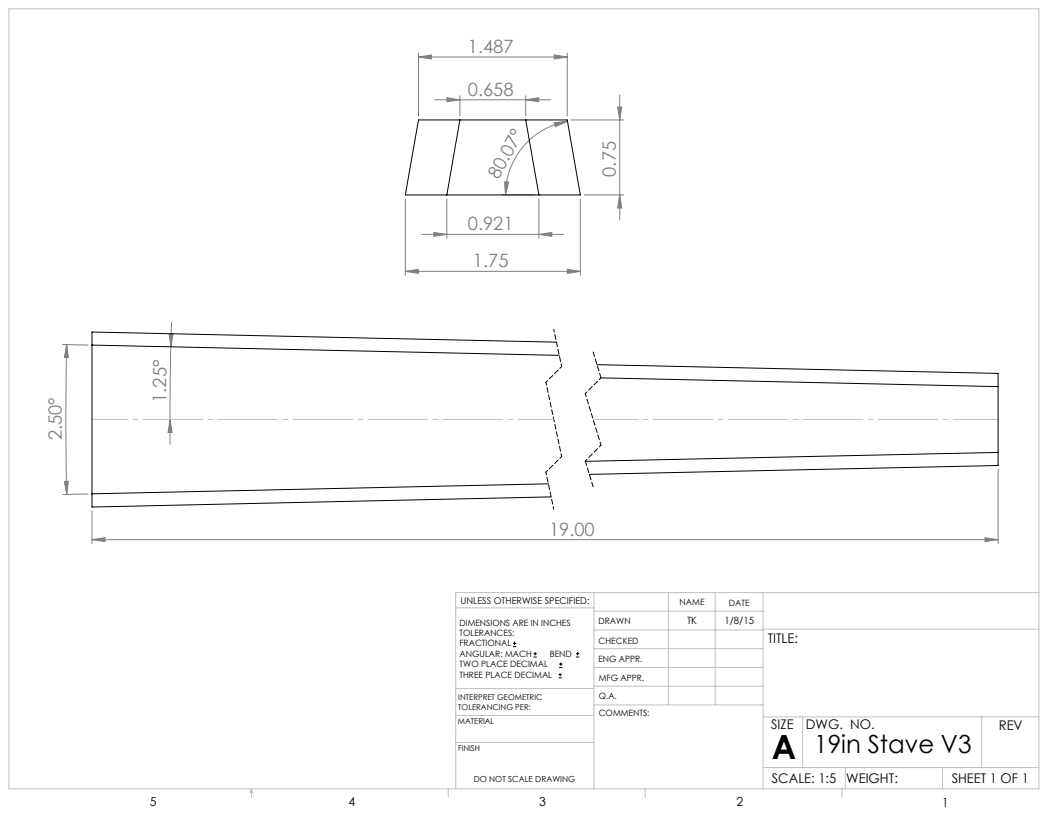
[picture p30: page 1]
19in Stave V3; SHEET 1 OF 1; SCALE: 1:5 WEIGHT:; DWG. NO.; REV; MFG APPR.; ENG APPR.; INTERPRET GEOMETRIC TOLERANCING PER:; ANGULAR: MACH; BEND

UNLESS OTHERWISE SPECIFIED:

DIMENSIONS ARE IN INCHES
TOLERANCES:
FRACTIONAL
TWO PLACE DECIMAL
THREE PLACE DECIMAL

DO NOT SCALE DRAWING

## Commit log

2026-04-25 update documents
    files organized and pushed
    [19in-Stave-V1.SLDPRT, 19in-Stave-V2.SLDPRT, 19in-Stave-V3.SLDDRW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]
2026-04-26 Add 2021 Mister Zephyr glue-up photo with process-longevity framing
    New "Glue-up — labeled staves, two-half clamping" subsection in
    Engineering artifacts, featuring the Oct 2021 Douglas Fir Ashiko
    #009 build. Caption highlights the two-half clamping technique,
    the inside-face maker's signature tradition (cross-linked to
    djembe), and frames the photo as evidence the 2015 workshop's
    process docs are still producing drums six years later.
2026-05-02 Add Segmented Ashiko design table from Musical Instruments workbook
    [ashiko-drum-workshop-design-table.xlsx]
2026-05-23 Recover from 2026-05-18 hygiene-bot stash; gitignore photo galleries (Stave Gallery / Turning Photos / Images)
    [12 Segment Wedgie.SLDPRT, 16 Seg 6 degree - Open Segmented Vessel Plate.SLDPRT, 16 Segment Wedgie.SLDPRT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]
2026-05-29 Add empirical tuning packet — validation log, acceptance checklist, visual register (Refs #1) (#2)
    - validation.csv: 16 workshop drums with nominal shell/head dimensions; measured pitch fields marked pending_measurement
    - reference/acoustic-validation-checklist.md: pre-build and post-build acceptance gates
    - visual-output-register.csv: archival workshop photos registered as reference_only
    - README.md: status line added (L4 V5 empirical packet)
    [validation.csv, visual-output-register.csv]
2026-05-31 Add image-gen concept prompt; wire explorer images
2026-05-31 Add explorer.html (design + Wolfram embed slot + concept-image gallery)
    Generated by wolfram-cloud-sync/generate_explorer.py.
2026-06-01 Wire 3 rendered concept image(s) into explorer gallery
2026-06-23 feat(wolfram): deploy interactive model + live explorer embed (#7)
    * Add V5 build packet: design, BOM, cut-list, assembly manual, Wolfram model, capstone manifest
    build/packet/ contains the full V5 layer on top of the existing workshop archive:
    design.md — stave geometry, compound miter method, wood species table, design decisions
    bom.csv — per-drum materials at 2015 bulk pricing (~$78/drum)
    sourcing.csv — supplier details for lumber, goatskin, rope, finish
    cut-list.csv — stave rip/miter parameters + clamping caul dimensions
    assembly-manual.md — 8-stage build process with tool references and tolerances
    risks.md — fabrication (stave variance, glue-up timing, lathe walk) + safety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
    [bom.csv, cut-list.csv, sourcing.csv]
2026-07-02 V5 packet refresh: status line, provenance, parametric OpenSCAD master, evolution intake
    - Normalize README Status line to approved value (kept L4 V5 empirical packet).
    - Mirror V5 root baseline files from build/packet/ (design, bom, sourcing,
    cut-list, risks, drawing-brief, assembly-manual).
    - Author CAD/ashiko-drum-workshop.scad parametric stave-shell envelope master
    (n=18 truncated-cone facets + head ring; foot_od/wall assumptions; compound-
    miter cut out of scope). openscad render check: pass (exit 0).
    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
    [ashiko-drum-workshop.scad, bom.csv, cut-list.csv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]
2026-07-03 chore: add .gitattributes for CRLF normalization + binary handling (#10)
    Adds the standard maker/CAD .gitattributes template (text=auto eol=lf,
    explicit LF for code/docs/config, binary excludes for CAD/image/office
    formats) so this repo stops being exposed to CRLF drift when edited by
    both Windows tools and WSL.
    Does NOT renormalize existing tracked blobs (git add --renormalize) —
    that is a deliberate, separately-reviewed follow-up per the tracking
    issue, to avoid a surprise mass line-ending diff in this PR.
    Refs tonykoop/instrument-maker#215
